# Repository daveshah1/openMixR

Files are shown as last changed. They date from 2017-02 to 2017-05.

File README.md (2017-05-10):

# openMixR 4k Mixed Reality Headset

openMixR is an open software/hardware mixed reality headset powered by an Artix-7 FPGA. It combines a high-resolution (4k) virtual reality headset with
4k cameras and a powerful FPGA to provide augmented reality experiences.

## Current Status

Last year as a university group project a low resolution prototype was built, capable of demos
including a 2D Minecraft game and overlaying content from an HDMI input.

PCB design for revision 1 of the 4k version - which this repo is for - has been finished and PCBs have now arrived. FPGA HDL for the cameras has been developed and tested (albeit
  with a different camera model only capable of 4k30, see [this repo](https://github.com/daveshah1/CSI2Rx)), and HDL for basic LCD functionality has been written
and undergone basic testing. To run the display at 4k will require feeding it with VESA DSC compressed video; code for
this is far from complete so I will be using the display at first in a mode where it upscales from 1080p - which
still looks a lot nicer than a native 1080p LCD. Current LCD code is [here](https://github.com/daveshah1/DSITx).

I am now in the process of testing the PCBs and writing a simple AR demo using the LCD and cameras. At present no breaking
issues in the rev 1.0 PCB have arisen although do take note a few minor errata points - see the hardware folder.

I am also working on a custom HLS tool, not yet released, that will be used to create much of the FPGA processing
code that runs on the headset. An early version of this was used for the aforementioned low res demos.

## Hardware Features

The main components of the hardware are:

 - 4k LCD repurposed from Z5 premium (AUO H546UAN01.0 or unknown Sharp part) on a subassembly allowing different LCDs to be used in the future
 - Dual OV16825 cameras, also on a subassembly so other cameras - in particular I am looking into the Sony IMX318 - could be used
 - Artix-7 FPGA (currently XC7A200T-3FBG484E but cheaper variants could be used)
 - Allwinner A64 quad-core ARM applications processor (with basic GPU for 3D rendering)
 - 512MB of DDR3 attached to the FPGA and 1GB attached to the A64 processor
 - WiFi and Bluetooth
 - USB-C for power, data and DisplayPort video

A photo of the assembled mainboard PCB is below:

Mainboard Photo

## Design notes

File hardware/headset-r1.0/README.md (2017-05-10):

# Hardware for openMixR 1.0

All of the hardware is designed in KiCad 4.0, in the spirit of open source.

- *mainboard* is the headset mainboard, containing the FPGA and processor. It is a 150x90mm 8-layer board
with a minimum track/space of 4mil and a controlled impedance requirement.
- *camboard* is the OV16825 camera subassembly
- *lcdboard* is the Z5 Premium LCD subassembly
- *usbbase* is a board that combines power, USB 2.0 data and Displayport into a USB-C connection,
so openMixR can be used if your computer doesn't support USB-C.

In addition, all of the libraries needed are included. Schematic component libraries are inside the
board folders, with the exception  of *customconn* which is the custom LCD and camera connectors that
interconnect the mainboard and subassemblies. *parts.pretty* contains all of the custom footprints; and *3d*
contains 3D models for many of the components used (for the most part converted from the models provided by their vendors).

PDF schematics are included for all of the boards, if you don't want to install KiCad. Gerbers are also included for all of the boards.

A bill of materials, placement data and impedance control diagrams are also included for the mainboard.

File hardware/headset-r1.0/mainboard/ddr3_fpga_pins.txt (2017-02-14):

##################################################################################################
##
##  Xilinx, Inc. 2010            www.xilinx.com
##  Mon Aug 29 11:18:27 2016
##  Generated by MIG Version 4.0
##
##################################################################################################
##  File name :       mig_7series_0.xdc
##  Details :     Constraints file
##                    FPGA Family:       ARTIX7
##                    FPGA Part:         XC7A100T-FGG484
##                    Speedgrade:        -3
##                    Design Entry:      VHDL
##                    Frequency:         0 MHz
##                    Time Period:       1875 ps
##################################################################################################

##################################################################################################
## Controller 0
## Memory Device: DDR3_SDRAM->Components->MT41K256M16XX-15E
## Data Width: 16
## Time Period: 1875
## Data Mask: 1
##################################################################################################

create_clock -period 2.813 [get_ports sys_clk_p]

#create_clock -period 5 [get_ports clk_ref_i]

############## NET - IOSTANDARD ##################

# PadFunction: IO_L20P_T3_35
set_property SLEW FAST [get_ports {ddr3_dq[0]}]
set_property IN_TERM UNTUNED_SPLIT_50 [get_ports {ddr3_dq[0]}]
set_property IOSTANDARD SSTL15 [get_ports {ddr3_dq[0]}]
set_property PACKAGE_PIN R1 [get_ports {ddr3_dq[0]}]

# PadFunction: IO_L20N_T3_35
set_property SLEW FAST [get_ports {ddr3_dq[1]}]
set_property IN_TERM UNTUNED_SPLIT_50 [get_ports {ddr3_dq[1]}]
set_property IOSTANDARD SSTL15 [get_ports {ddr3_dq[1]}]
set_property PACKAGE_PIN P1 [get_ports {ddr3_dq[1]}]

# PadFunction: IO_L22P_T3_35
set_property SLEW FAST [get_ports {ddr3_dq[2]}]
set_property IN_TERM UNTUNED_SPLIT_50 [get_ports {ddr3_dq[2]}]
set_property IOSTANDARD SSTL15 [get_ports {ddr3_dq[2]}]
set_property PACKAGE_PIN P2 [get_ports {ddr3_dq[2]}]

# PadFunction: IO_L22N_T3_35
set_property SLEW FAST [get_ports {ddr3_dq[3]}]
set_property IN_TERM UNTUNED_SPLIT_50 [get_ports {ddr3_dq[3]}]
set_property IOSTANDARD SSTL15 [get_ports {ddr3_dq[3]}]
set_property PACKAGE_PIN N2 [get_ports {ddr3_dq[3]}]

# PadFunction: IO_L23P_T3_35
set_property SLEW FAST [get_ports {ddr3_dq[4]}]
set_property IN_TERM UNTUNED_SPLIT_50 [get_ports {ddr3_dq[4]}]
set_property IOSTANDARD SSTL15 [get_ports {ddr3_dq[4]}]
set_property PACKAGE_PIN M6 [get_ports {ddr3_dq[4]}]

# PadFunction: IO_L23N_T3_35
set_property SLEW FAST [get_ports {ddr3_dq[5]}]
set_property IN_TERM UNTUNED_SPLIT_50 [get_ports {ddr3_dq[5]}]
set_property IOSTANDARD SSTL15 [get_ports {ddr3_dq[5]}]
set_property PACKAGE_PIN M5 [get_ports {ddr3_dq[5]}]

# PadFunction: IO_L24P_T3_35
set_property SLEW FAST [get_ports {ddr3_dq[6]}]
set_property IN_TERM UNTUNED_SPLIT_50 [get_ports {ddr3_dq[6]}]
set_property IOSTANDARD SSTL15 [get_ports {ddr3_dq[6]}]
set_property PACKAGE_PIN P6 [get_ports {ddr3_dq[6]}]

# PadFunction: IO_L24N_T3_35
set_property SLEW FAST [get_ports {ddr3_dq[7]}]
set_property IN_TERM UNTUNED_SPLIT_50 [get_ports {ddr3_dq[7]}]
set_property IOSTANDARD SSTL15 [get_ports {ddr3_dq[7]}]
set_property PACKAGE_PIN N5 [get_ports {ddr3_dq[7]}]

# PadFunction: IO_L1N_T0_34
set_property SLEW FAST [get_ports {ddr3_dq[8]}]
set_property IN_TERM UNTUNED_SPLIT_50 [get_ports {ddr3_dq[8]}]
set_property IOSTANDARD SSTL15 [get_ports {ddr3_dq[8]}]
set_property PACKAGE_PIN U1 [get_ports {ddr3_dq[8]}]

# PadFunction: IO_L2P_T0_34
set_property SLEW FAST [get_ports {ddr3_dq[9]}]
set_property IN_TERM UNTUNED_SPLIT_50 [get_ports {ddr3_dq[9]}]
set_property IOSTANDARD SSTL15 [get_ports {ddr3_dq[9]}]
set_property PACKAGE_PIN U2 [get_ports {ddr3_dq[9]}]

# PadFunction: IO_L2N_T0_34
set_property SLEW FAST [get_ports {ddr3_dq[10]}]
set_property IN_TERM UNTUNED_SPLIT_50 [get_ports {ddr3_dq[10]}]
set_property IOSTANDARD SSTL15 [get_ports {ddr3_dq[10]}]
set_property PACKAGE_PIN V2 [get_ports {ddr3_dq[10]}]

# PadFunction: IO_L4P_T0_34
set_property SLEW FAST [get_ports {ddr3_dq[11]}]
set_property IN_TERM UNTUNED_SPLIT_50 [get_ports {ddr3_dq[11]}]
set_property IOSTANDARD SSTL15 [get_ports {ddr3_dq[11]}]
set_property PACKAGE_PIN W2 [get_ports {ddr3_dq[11]}]

# PadFunction: IO_L4N_T0_34
set_property SLEW FAST [get_ports {ddr3_dq[12]}]
set_property IN_TERM UNTUNED_SPLIT_50 [get_ports {ddr3_dq[12]}]
set_property IOSTANDARD SSTL15 [get_ports {ddr3_dq[12]}]
set_property PACKAGE_PIN Y2 [get_ports {ddr3_dq[12]}]

# PadFunction: IO_L5P_T0_34
set_property SLEW FAST [get_ports {ddr3_dq[13]}]
set_property IN_TERM UNTUNED_SPLIT_50 [get_ports {ddr3_dq[13]}]
set_property IOSTANDARD SSTL15 [get_ports {ddr3_dq[13]}]
set_property PACKAGE_PIN W1 [get_ports {ddr3_dq[13]}]

# PadFunction: IO_L5N_T0_34
set_property SLEW FAST [get_ports {ddr3_dq[14]}]
set_property IN_TERM UNTUNED_SPLIT_50 [get_ports {ddr3_dq[14]}]
set_property IOSTANDARD SSTL15 [get_ports {ddr3_dq[14]}]
set_property PACKAGE_PIN Y1 [get_ports {ddr3_dq[14]}]

# PadFunction: IO_L6P_T0_34
set_property SLEW FAST [get_ports {ddr3_dq[15]}]
set_property IN_TERM UNTUNED_SPLIT_50 [get_ports {ddr3_dq[15]}]
set_property IOSTANDARD SSTL15 [get_ports {ddr3_dq[15]}]
set_property PACKAGE_PIN U3 [get_ports {ddr3_dq[15]}]

# PadFunction: IO_L1P_T0_AD4P_35
set_property SLEW FAST [get_ports {ddr3_addr[14]}]
set_property IOSTANDARD SSTL15 [get_ports {ddr3_addr[14]}]
set_property PACKAGE_PIN B1 [get_ports {ddr3_addr[14]}]

# PadFunction: IO_L1N_T0_AD4N_35
set_property SLEW FAST [get_ports {ddr3_addr[13]}]
set_property IOSTANDARD SSTL15 [get_ports {ddr3_addr[13]}]
set_property PACKAGE_PIN A1 [get_ports {ddr3_addr[13]}]

# PadFunction: IO_L2P_T0_AD12P_35
set_property SLEW FAST [get_ports {ddr3_addr[12]}]
set_property IOSTANDARD SSTL15 [get_ports {ddr3_addr[12]}]
set_property PACKAGE_PIN C2 [get_ports {ddr3_addr[12]}]

# PadFunction: IO_L2N_T0_AD12N_35
set_property SLEW FAST [get_ports {ddr3_addr[11]}]
set_property IOSTANDARD SSTL15 [get_ports {ddr3_addr[11]}]
set_property PACKAGE_PIN B2 [get_ports {ddr3_addr[11]}]

# PadFunction: IO_L4P_T0_35
set_property SLEW FAST [get_ports {ddr3_addr[10]}]
set_property IOSTANDARD SSTL15 [get_ports {ddr3_addr[10]}]
set_property PACKAGE_PIN E2 [get_ports {ddr3_addr[10]}]

# PadFunction: IO_L4N_T0_35
set_property SLEW FAST [get_ports {ddr3_addr[9]}]
set_property IOSTANDARD SSTL15 [get_ports {ddr3_addr[9]}]
set_property PACKAGE_PIN D2 [get_ports {ddr3_addr[9]}]

# PadFunction: IO_L5P_T0_AD13P_35
set_property SLEW FAST [get_ports {ddr3_addr[8]}]
set_property IOSTANDARD SSTL15 [get_ports {ddr3_addr[8]}]
set_property PACKAGE_PIN G1 [get_ports {ddr3_addr[8]}]

# PadFunction: IO_L5N_T0_AD13N_35
set_property SLEW FAST [get_ports {ddr3_addr[7]}]
set_property IOSTANDARD SSTL15 [get_ports {ddr3_addr[7]}]
set_property PACKAGE_PIN F1 [get_ports {ddr3_addr[7]}]

# PadFunction: IO_L6P_T0_35
set_property SLEW FAST [get_ports {ddr3_addr[6]}]
set_property IOSTANDARD SSTL15 [get_ports {ddr3_addr[6]}]
set_property PACKAGE_PIN F3 [get_ports {ddr3_addr[6]}]

# PadFunction: IO_L7P_T1_AD6P_35
set_property SLEW FAST [get_ports {ddr3_addr[5]}]
set_property IOSTANDARD SSTL15 [get_ports {ddr3_addr[5]}]
set_property PACKAGE_PIN K1 [get_ports {ddr3_addr[5]}]

# PadFunction: IO_L7N_T1_AD6N_35
set_property SLEW FAST [get_ports {ddr3_addr[4]}]
set_property IOSTANDARD SSTL15 [get_ports {ddr3_addr[4]}]
set_property PACKAGE_PIN J1 [get_ports {ddr3_addr[4]}]

# PadFunction: IO_L8P_T1_AD14P_35
set_property SLEW FAST [get_ports {ddr3_addr[3]}]
set_property IOSTANDARD SSTL15 [get_ports {ddr3_addr[3]}]
set_property PACKAGE_PIN H2 [get_ports {ddr3_addr[3]}]

# PadFunction: IO_L8N_T1_AD14N_35
set_property SLEW FAST [get_ports {ddr3_addr[2]}]
set_property IOSTANDARD SSTL15 [get_ports {ddr3_addr[2]}]
set_property PACKAGE_PIN G2 [get_ports {ddr3_addr[2]}]

# PadFunction: IO_L9P_T1_DQS_AD7P_35
set_property SLEW FAST [get_ports {ddr3_addr[1]}]
set_property IOSTANDARD SSTL15 [get_ports {ddr3_addr[1]}]
set_property PACKAGE_PIN K2 [get_ports {ddr3_addr[1]}]

# PadFunction: IO_L9N_T1_DQS_AD7N_35
set_property SLEW FAST [get_ports {ddr3_addr[0]}]
set_property IOSTANDARD SSTL15 [get_ports {ddr3_addr[0]}]
set_property PACKAGE_PIN J2 [get_ports {ddr3_addr[0]}]

# PadFunction: IO_L10P_T1_AD15P_35
set_property SLEW FAST [get_ports {ddr3_ba[2]}]
set_property IOSTANDARD SSTL15 [get_ports {ddr3_ba[2]}]
set_property PACKAGE_PIN J5 [get_ports {ddr3_ba[2]}]

# PadFunction: IO_L10N_T1_AD15N_35
set_property SLEW FAST [get_ports {ddr3_ba[1]}]
set_property IOSTANDARD SSTL15 [get_ports {ddr3_ba[1]}]
set_property PACKAGE_PIN H5 [get_ports {ddr3_ba[1]}]

# PadFunction: IO_L11P_T1_SRCC_35
set_property SLEW FAST [get_ports {ddr3_ba[0]}]
set_property IOSTANDARD SSTL15 [get_ports {ddr3_ba[0]}]
set_property PACKAGE_PIN H3 [get_ports {ddr3_ba[0]}]

# PadFunction: IO_L11N_T1_SRCC_35
set_property SLEW FAST [get_ports {ddr3_ras_n}]
set_property IOSTANDARD SSTL15 [get_ports {ddr3_ras_n}]
set_property PACKAGE_PIN G3 [get_ports {ddr3_ras_n}]

# PadFunction: IO_L12P_T1_MRCC_35
set_property SLEW FAST [get_ports {ddr3_cas_n}]
set_property IOSTANDARD SSTL15 [get_ports {ddr3_cas_n}]
set_property PACKAGE_PIN H4 [get_ports {ddr3_cas_n}]

# PadFunction: IO_L12N_T1_MRCC_35
set_property SLEW FAST [get_ports {ddr3_we_n}]
set_property IOSTANDARD SSTL15 [get_ports {ddr3_we_n}]
set_property PACKAGE_PIN G4 [get_ports {ddr3_we_n}]

# PadFunction: IO_L13P_T2_MRCC_35
set_property SLEW FAST [get_ports {ddr3_reset_n}]
set_property IOSTANDARD LVCMOS15 [get_ports {ddr3_reset_n}]
set_property PACKAGE_PIN K4 [get_ports {ddr3_reset_n}]

# PadFunction: IO_L15N_T2_DQS_35
set_property SLEW FAST [get_ports {ddr3_cke[0]}]
set_property IOSTANDARD SSTL15 [get_ports {ddr3_cke[0]}]
set_property PACKAGE_PIN L1 [get_ports {ddr3_cke[0]}]

# PadFunction: IO_L16P_T2_35
set_property SLEW FAST [get_ports {ddr3_odt[0]}]
set_property IOSTANDARD SSTL15 [get_ports {ddr3_odt[0]}]
set_property PACKAGE_PIN M3 [get_ports {ddr3_odt[0]}]

# PadFunction: IO_L15P_T2_DQS_35
set_property SLEW FAST [get_ports {ddr3_cs_n[0]}]
set_property IOSTANDARD SSTL15 [get_ports {ddr3_cs_n[0]}]
set_property PACKAGE_PIN M1 [get_ports {ddr3_cs_n[0]}]

# PadFunction: IO_L19P_T3_35
set_property SLEW FAST [get_ports {ddr3_dm[0]}]
set_property IOSTANDARD SSTL15 [get_ports {ddr3_dm[0]}]
set_property PACKAGE_PIN N4 [get_ports {ddr3_dm[0]}]

# PadFunction: IO_L1P_T0_34
set_property SLEW FAST [get_ports {ddr3_dm[1]}]
set_property IOSTANDARD SSTL15 [get_ports {ddr3_dm[1]}]
set_property PACKAGE_PIN T1 [get_ports {ddr3_dm[1]}]

# PadFunction: IO_L14P_T2_SRCC_35
set_property IOSTANDARD DIFF_SSTL15 [get_ports {sys_clk_p}]
set_property PACKAGE_PIN L3 [get_ports {sys_clk_p}]

# PadFunction: IO_L14N_T2_SRCC_35
set_property IOSTANDARD DIFF_SSTL15 [get_ports {sys_clk_n}]
set_property PACKAGE_PIN K3 [get_ports {sys_clk_n}]

# PadFunction: IO_L21P_T3_DQS_35
set_property SLEW FAST [get_ports {ddr3_dqs_p[0]}]
set_property IN_TERM UNTUNED_SPLIT_50 [get_ports {ddr3_dqs_p[0]}]
set_property IOSTANDARD DIFF_SSTL15 [get_ports {ddr3_dqs_p[0]}]
set_property PACKAGE_PIN P5 [get_ports {ddr3_dqs_p[0]}]

# PadFunction: IO_L21N_T3_DQS_35
set_property SLEW FAST [get_ports {ddr3_dqs_n[0]}]
set_property IN_TERM UNTUNED_SPLIT_50 [get_ports {ddr3_dqs_n[0]}]
set_property IOSTANDARD DIFF_SSTL15 [get_ports {ddr3_dqs_n[0]}]
set_property PACKAGE_PIN P4 [get_ports {ddr3_dqs_n[0]}]

# PadFunction: IO_L3P_T0_DQS_34
set_property SLEW FAST [get_ports {ddr3_dqs_p[1]}]
set_property IN_TERM UNTUNED_SPLIT_50 [get_ports {ddr3_dqs_p[1]}]
set_property IOSTANDARD DIFF_SSTL15 [get_ports {ddr3_dqs_p[1]}]
set_property PACKAGE_PIN R3 [get_ports {ddr3_dqs_p[1]}]

# PadFunction: IO_L3N_T0_DQS_34
set_property SLEW FAST [get_ports {ddr3_dqs_n[1]}]
set_property IN_TERM UNTUNED_SPLIT_50 [get_ports {ddr3_dqs_n[1]}]
set_property IOSTANDARD DIFF_SSTL15 [get_ports {ddr3_dqs_n[1]}]
set_property PACKAGE_PIN R2 [get_ports {ddr3_dqs_n[1]}]

# PadFunction: IO_L3P_T0_DQS_AD5P_35
set_property SLEW FAST [get_ports {ddr3_ck_p[0]}]
set_property IOSTANDARD DIFF_SSTL15 [get_ports {ddr3_ck_p[0]}]
set_property PACKAGE_PIN E1 [get_ports {ddr3_ck_p[0]}]

# PadFunction: IO_L3N_T0_DQS_AD5N_35
set_property SLEW FAST [get_ports {ddr3_ck_n[0]}]
set_property IOSTANDARD DIFF_SSTL15 [get_ports {ddr3_ck_n[0]}]
set_property PACKAGE_PIN D1 [get_ports {ddr3_ck_n[0]}]

set_property LOC PHASER_OUT_PHY_X1Y7 [get_cells  -hier -filter {NAME =~ */ddr_phy_4lanes_1.u_ddr_phy_4lanes/ddr_byte_lane_D.ddr_byte_lane_D/phaser_out}]
set_property LOC PHASER_OUT_PHY_X1Y11 [get_cells  -hier -filter {NAME =~ */ddr_phy_4lanes_0.u_ddr_phy_4lanes/ddr_byte_lane_D.ddr_byte_lane_D/phaser_out}]
set_property LOC PHASER_OUT_PHY_X1Y10 [get_cells  -hier -filter {NAME =~ */ddr_phy_4lanes_0.u_ddr_phy_4lanes/ddr_byte_lane_C.ddr_byte_lane_C/phaser_out}]
set_property LOC PHASER_OUT_PHY_X1Y9 [get_cells  -hier -filter {NAME =~ */ddr_phy_4lanes_0.u_ddr_phy_4lanes/ddr_byte_lane_B.ddr_byte_lane_B/phaser_out}]
set_property LOC PHASER_OUT_PHY_X1Y8 [get_cells  -hier -filter {NAME =~ */ddr_phy_4lanes_0.u_ddr_phy_4lanes/ddr_byte_lane_A.ddr_byte_lane_A/phaser_out}]

set_property LOC PHASER_IN_PHY_X1Y7 [get_cells  -hier -filter {NAME =~ */ddr_phy_4lanes_1.u_ddr_phy_4lanes/ddr_byte_lane_D.ddr_byte_lane_D/phaser_in_gen.phaser_in}]
## set_property LOC PHASER_IN_PHY_X1Y11 [get_cells  -hier -filter {NAME =~ */ddr_phy_4lanes_0.u_ddr_phy_4lanes/ddr_byte_lane_D.ddr_byte_lane_D/phaser_in_gen.phaser_in}]
## set_property LOC PHASER_IN_PHY_X1Y10 [get_cells  -hier -filter {NAME =~ */ddr_phy_4lanes_0.u_ddr_phy_4lanes/ddr_byte_lane_C.ddr_byte_lane_C/phaser_in_gen.phaser_in}]
## set_property LOC PHASER_IN_PHY_X1Y9 [get_cells  -hier -filter {NAME =~ */ddr_phy_4lanes_0.u_ddr_phy_4lanes/ddr_byte_lane_B.ddr_byte_lane_B/phaser_in_gen.phaser_in}]
set_property LOC PHASER_IN_PHY_X1Y8 [get_cells  -hier -filter {NAME =~ */ddr_phy_4lanes_0.u_ddr_phy_4lanes/ddr_byte_lane_A.ddr_byte_lane_A/phaser_in_gen.phaser_in}]

set_property LOC OUT_FIFO_X1Y7 [get_cells  -hier -filter {NAME =~ */ddr_phy_4lanes_1.u_ddr_phy_4lanes/ddr_byte_lane_D.ddr_byte_lane_D/out_fifo}]
set_property LOC OUT_FIFO_X1Y11 [get_cells  -hier -filter {NAME =~ */ddr_phy_4lanes_0.u_ddr_phy_4lanes/ddr_byte_lane_D.ddr_byte_lane_D/out_fifo}]
set_property LOC OUT_FIFO_X1Y10 [get_cells  -hier -filter {NAME =~ */ddr_phy_4lanes_0.u_ddr_phy_4lanes/ddr_byte_lane_C.ddr_byte_lane_C/out_fifo}]
set_property LOC OUT_FIFO_X1Y9 [get_cells  -hier -filter {NAME =~ */ddr_phy_4lanes_0.u_ddr_phy_4lanes/ddr_byte_lane_B.ddr_byte_lane_B/out_fifo}]
set_property LOC OUT_FIFO_X1Y8 [get_cells  -hier -filter {NAME =~ */ddr_phy_4lanes_0.u_ddr_phy_4lanes/ddr_byte_lane_A.ddr_byte_lane_A/out_fifo}]

set_property LOC IN_FIFO_X1Y7 [get_cells  -hier -filter {NAME =~ */ddr_phy_4lanes_1.u_ddr_phy_4lanes/ddr_byte_lane_D.ddr_byte_lane_D/in_fifo_gen.in_fifo}]
set_property LOC IN_FIFO_X1Y8 [get_cells  -hier -filter {NAME =~ */ddr_phy_4lanes_0.u_ddr_phy_4lanes/ddr_byte_lane_A.ddr_byte_lane_A/in_fifo_gen.in_fifo}]

set_property LOC PHY_CONTROL_X1Y1 [get_cells  -hier -filter {NAME =~ */ddr_phy_4lanes_1.u_ddr_phy_4lanes/phy_control_i}]
set_property LOC PHY_CONTROL_X1Y2 [get_cells  -hier -filter {NAME =~ */ddr_phy_4lanes_0.u_ddr_phy_4lanes/phy_control_i}]

set_property LOC PHASER_REF_X1Y1 [get_cells  -hier -filter {NAME =~ */ddr_phy_4lanes_1.u_ddr_phy_4lanes/phaser_ref_i}]
set_property LOC PHASER_REF_X1Y2 [get_cells  -hier -filter {NAME =~ */ddr_phy_4lanes_0.u_ddr_phy_4lanes/phaser_ref_i}]

set_property LOC OLOGIC_X1Y93 [get_cells  -hier -filter {NAME =~ */ddr_phy_4lanes_1.u_ddr_phy_4lanes/ddr_byte_lane_D.ddr_byte_lane_D/ddr_byte_group_io/*slave_ts}]
set_property LOC OLOGIC_X1Y107 [get_cells  -hier -filter {NAME =~ */ddr_phy_4lanes_0.u_ddr_phy_4lanes/ddr_byte_lane_A.ddr_byte_lane_A/ddr_byte_group_io/*slave_ts}]

set_property LOC PLLE2_ADV_X1Y2 [get_cells -hier -filter {NAME =~ */u_ddr3_infrastructure/plle2_i}]
set_property LOC MMCME2_ADV_X1Y2 [get_cells -hier -filter {NAME =~ */u_ddr3_infrastructure/gen_mmcm.mmcm_i}]

set_multicycle_path -from [get_cells -hier -filter {NAME =~ */mc0/mc_read_idle_r_reg}] \
                    -to   [get_cells -hier -filter {NAME =~ */input_[?].iserdes_dq_.iserdesdq}] \
                    -setup 6

set_multicycle_path -from [get_cells -hier -filter {NAME =~ */mc0/mc_read_idle_r_reg}] \
                    -to   [get_cells -hier -filter {NAME =~ */input_[?].iserdes_dq_.iserdesdq}] \
                    -hold 5

set_false_path -through [get_pins -filter {NAME =~ */DQSFOUND} -of [get_cells -hier -filter {REF_NAME == PHASER_IN_PHY}]]

set_multicycle_path -through [get_pins -filter {NAME =~ */OSERDESRST} -of [get_cells -hier -filter {REF_NAME == PHASER_OUT_PHY}]] -setup 2 -start
set_multicycle_path -through [get_pins -filter {NAME =~ */OSERDESRST} -of [get_cells -hier -filter {REF_NAME == PHASER_OUT_PHY}]] -hold 1 -start

set_max_delay -datapath_only -from [get_cells -hier -filter {NAME =~ *temp_mon_enabled.u_tempmon/* && IS_SEQUENTIAL}] -to [get_cells -hier -filter {NAME =~ *temp_mon_enabled.u_tempmon/device_temp_sync_r1*}] 20
set_max_delay -from [get_cells -hier *rstdiv0_sync_r1_reg*] -to [get_pins -filter {NAME =~ */RESET} -of [get_cells -hier -filter {REF_NAME == PHY_CONTROL}]] -datapath_only 5
set_false_path -through [get_pins -hier -filter {NAME =~ */u_iodelay_ctrl/sys_rst}]

set_max_delay -datapath_only -from [get_cells -hier -filter {NAME =~ *ddr3_infrastructure/rstdiv0_sync_r1_reg*}] -to [get_cells -hier -filter {NAME =~ *temp_mon_enabled.u_tempmon/xadc_supplied_temperature.rst_r1*}] 20

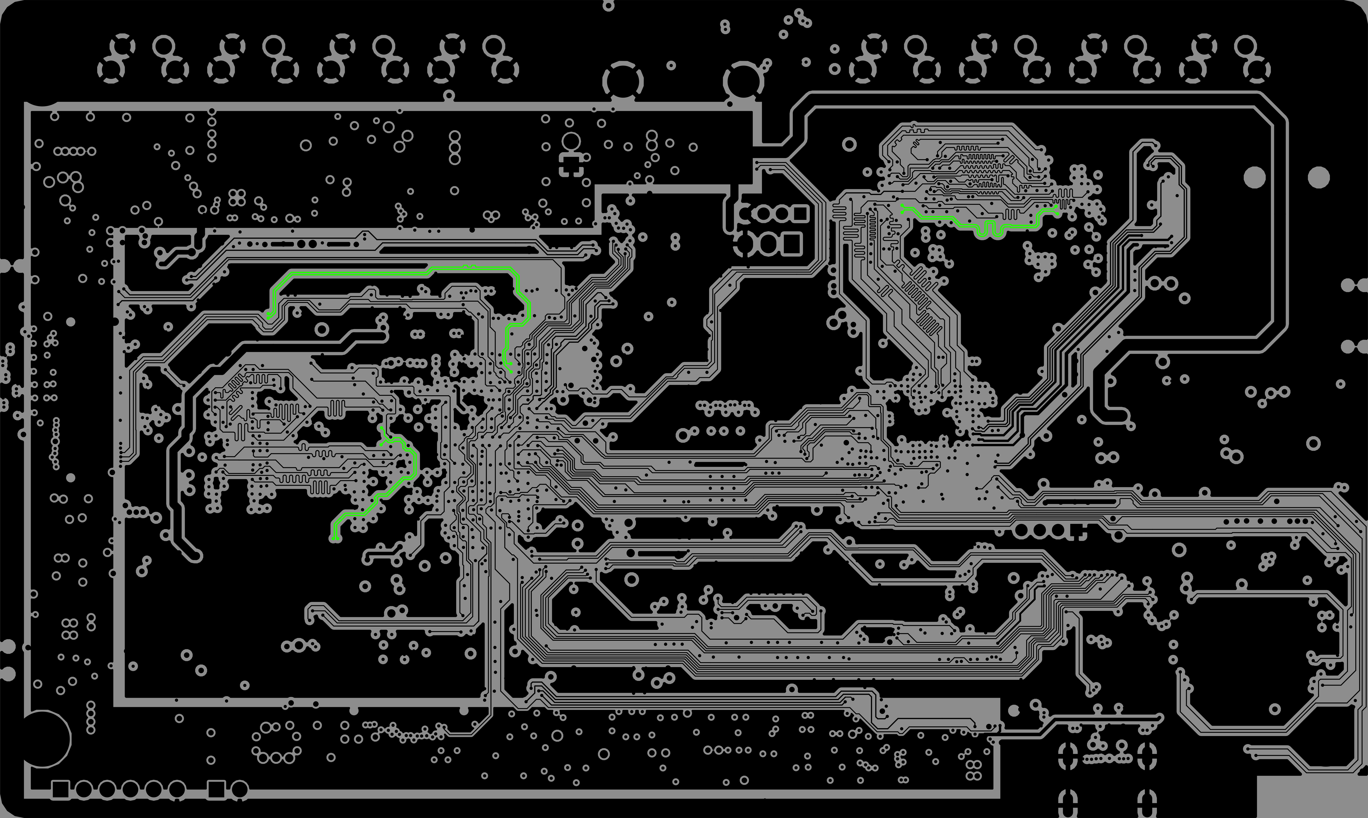
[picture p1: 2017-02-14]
hardware/headset-r1.0/mainboard/impedance/mainboard-In2.Cu-imp.png

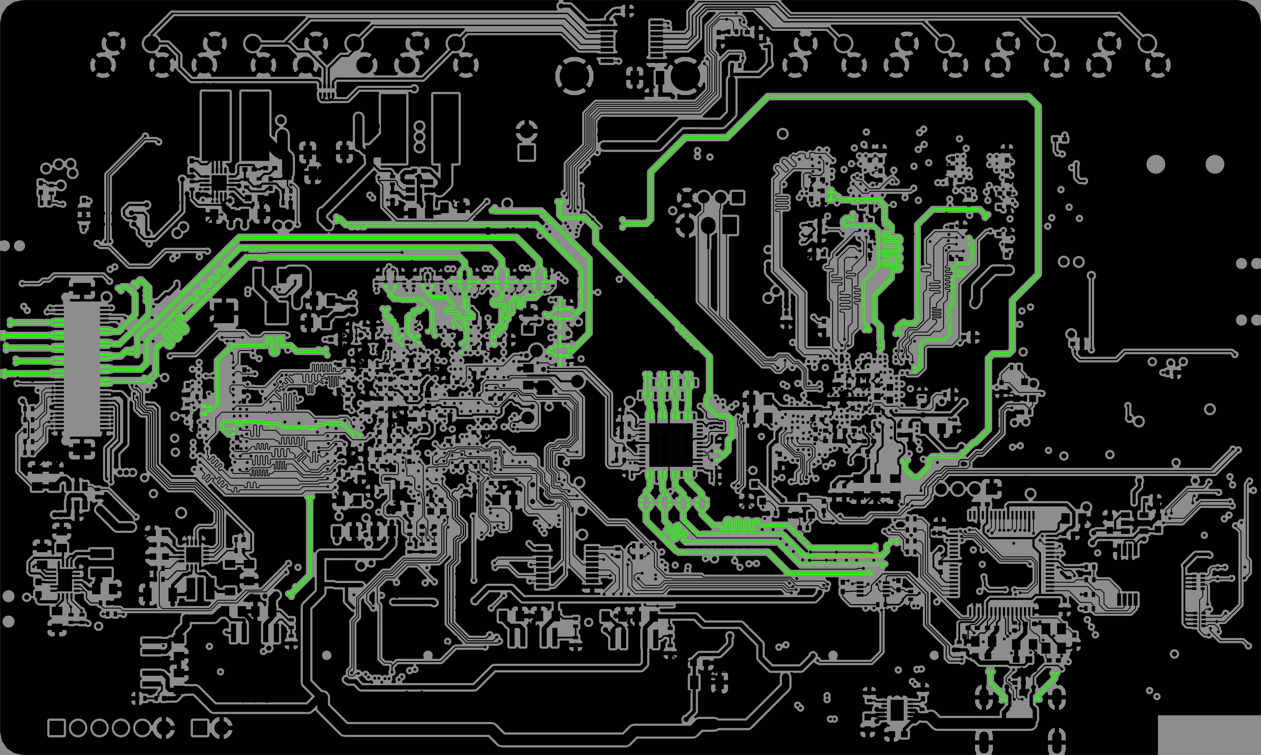
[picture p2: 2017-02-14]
hardware/headset-r1.0/mainboard/impedance/mainboard-B.Cu-imp.png

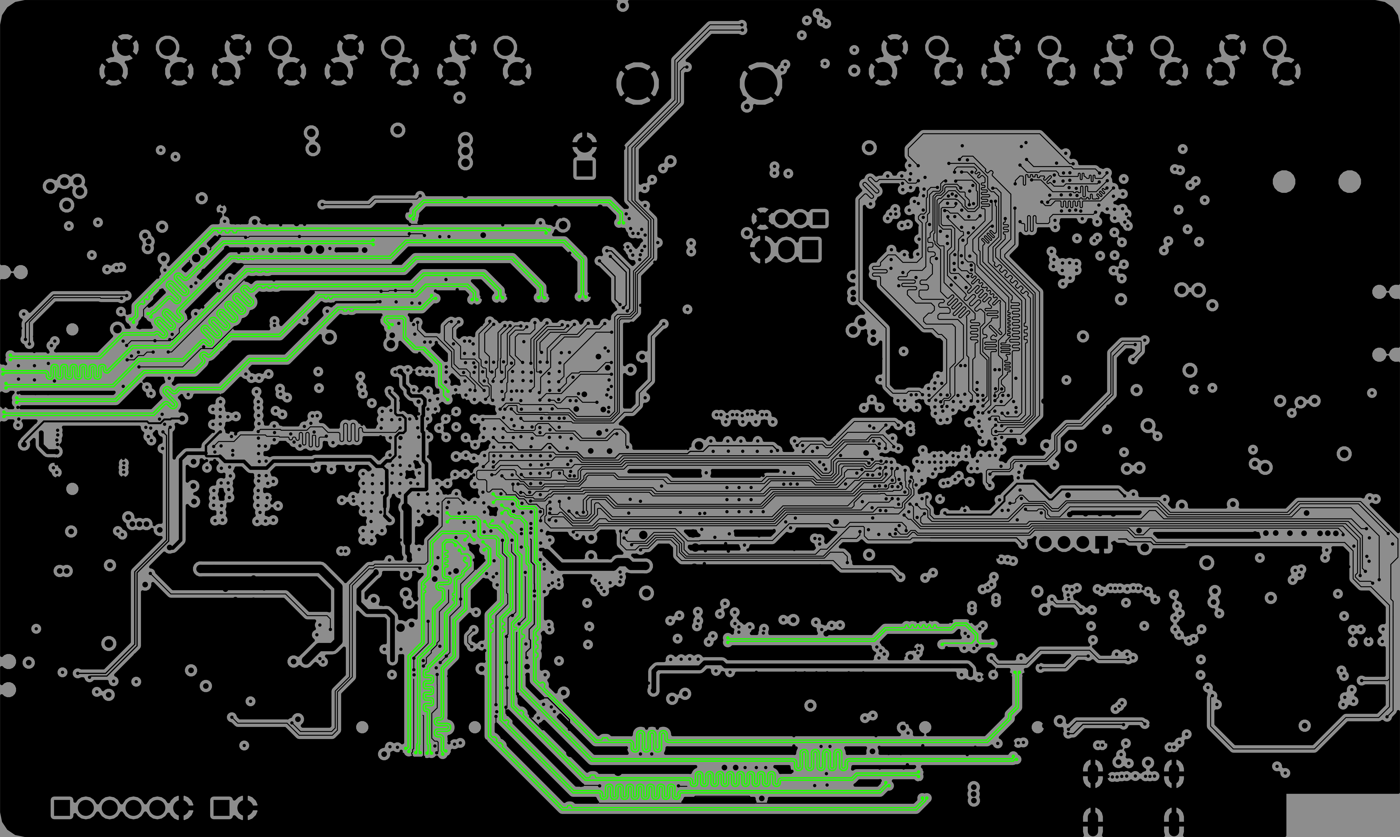
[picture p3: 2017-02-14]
hardware/headset-r1.0/mainboard/impedance/mainboard-In5.Cu-imp.png

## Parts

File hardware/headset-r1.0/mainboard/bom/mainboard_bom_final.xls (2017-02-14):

Id | Designator | Package | Quantity | Designation | Description | Manufacturer | MPN | Notes | Pin/Pad Count | Line Pin/Pad Count
1 | D1901 | LED_RGB_5050 | 1 | QBLP679E-RGB | RGB LED PLCC6 5x5mm | QT Brightek | QBLP679E-RGB | or any other equivalent part | 6 | 6
2 | R1521 | R_0402 | 1 | 20k | 20kΩ 1% 0402 resistor | Yageo | RC0402FR-0720KL | or any other equivalent part | 2 | 2
3 | R1517,R1525 | R_0402 | 2 | 2.87k | 2.87kΩ 1% 0402 resistor | Yageo | RC0402FR-072K87L | or any other equivalent part | 2 | 4
4 | L1505,L1502 | VLP8040 | 2 | 1µH/VLP8040T-1R0 | 1µH 9A 8.6x8.6mm inductor | TDK | VLP8040T-1R0 | or any other equivalent part | 2 | 4
5 | C1516,C203,C205,C206,C207,C208,C211,C633,C634,C719,C1403,C1504,C1508,C1532,C1611,C237 | C_0603 | 16 | 1µ | 1µF 0603 X7R capacitor | Taiyo Yuden | EMK107B7105KA-T | or any other equivalent part | 2 | 32
6 | R1614,R202,R704,R1201,R1202,R1407,R1408,R1410,R1412,R1414,R1512,R221 | R_0402 | 12 | 4.64k | 4.64kΩ 1% 0402 resistor | Yageo | RC0402FR-074K64L | or any other equivalent part | 2 | 24
7 | R1301,R505,R1424,R1207 | R_0402 | 4 | 100 | 100Ω 1% 0402 resistor | Yageo | RC0402FR-07100RL | or any other equivalent part | 2 | 8
8 | U1507,U1503 | QFN-16-1EP_3x3mm_Pitch0.5mm | 2 | TPS53316RGTR | Buck regulator IC | TI | TPS53316RGTR |  | 17 | 34
9 | C1502,C301,C302,C303,C304,C613,C614,C617,C618,C619,C620,C621,C622,C623,C624,C625,C636,C1503,C1505,C1520,C1528,C1538,C1539,C1540,C1602,C1604,C227 | C_0805 | 27 | 10µ | 10µF 0805 capacitor | Murata | GRM21BR71A106MA73L | or any other equivalent part | 2 | 54
10 | C1202,C527,C502,C503,C504,C505,C506,C507,C508,C509,C510,C511,C512,C513,C514,C515,C516,C517,C518,C519,C520,C521,C522,C523,C524,C525,C526,C528,C529,C530,C531,C532,C533,C534,C535,C536,C537,C640,C643,C645,C646,C647,C648,C649,C650,C651,C703,C712,C714,C723,C724,C725,C726,C727,C803,C807,C812,C818,C820,C823,C824,C902,C903,C904,C905,C1101,C1102,C1104,C1107,C1110,C1114,C1115,C1117,C1118,C1119,C1121,C1122,C1124,C1125,C1127,C1128,C1201,C1205,C1206,C1207,C1208,C1209,C1210,C1211,C1212,C1213,C1214,C1215,C1216,C1217,C1307,C1308,C1309,C1310,C1311,C1312,C1313,C1314,C1319,C1320,C1321,C1322,C1323,C1324,C1325,C1326,C1333,C1334,C1336,C1342,C1351,C1352,C1353,C1354,C1601 | C_0402 | 120 | 470n | 470nF 6.3V 0402 capacitor | Murata | GRM155C80J474KE19D | or any other equivalent part | 2 | 240
11 | U1201,U502,U503 | BGA_96_0.8mm | 3 | AS4C256M16D3A-12BCN | 256Mx16 800MHz DDR3 1.5V | Alliance Memory | AS4C256M16D3A-12BCN | can substitute with equivalent DDR3 e.g. | 96 | 288
12 | C639,C221,C224,C225,C501,C638,C641,C642,C644,C701,C711,C713,C715,C718,C720,C721,C801,C805,C821,C822,C901,C1105,C1120,C1303,C1304,C1305,C1306,C1316,C1317,C1318,C1328,C1329,C1331,C1335,C1349,C1350,C1402,C1506,C1522,C1529,C1603,C1606,C1607,C1608,C1612,C1544,C1545 | C_0805 | 47 | 4.7µ | 4.7µF 10V 0805 X7R capacitor | Murata | GRM21BR71A475KA73K | or any other equivalent part | 2 | 94
13 | R502,R506,R507,R1205,R1206 | R_0402 | 5 | 240 | 240kΩ 1% 0402 resistor | Yageo | RC0402FR-07240KL | or any other equivalent part | 2 | 10
14 | U501 | A64_BGA_396 | 1 | A64 | Allwinner A64 Cortex-A53 SoC | Allwinner | A64 |  | 396 | 396
15 | C1330,C1332,C717,C1355,C1356,C1357,C228,C229,C230,C231,C233,C234,C235,C236,C238,C239,C240,C241,C242,C243,C244,C245,C1337,C1338,C1339,C1340,C1341,C1343,C1344,C1345,C1346,C1347,C1358,C1359,C1360 | C_0201 | 35 | 100n | 100nF 0201 capacitor | Murata | GRM033C80J104ME15D | or any other equivalent part | 2 | 70
16 | U1101 | BGA_FGG_484 | 1 | XC7A200T-3FBG484E | Artix-7 FPGA 215k logic cells | Xilinx | XC7A200T-3FBG484E | can substitute with C or I grade | 484 | 484
17 | A801 | 2450AT43B100E | 1 | 2450AT43B100E | 2.4GHz chip antenna | Johanson | 2450AT43B100E |  | 4 | 4
18 | C202,C709,C1203,C1204,C1404,C1405,C1501,C1609 | C_0603 | 8 | 470n | 470nF 16V 0603 X7R capacitor | Taiyo Yuden | EMK107B7474KA-T | or any other equivalent part | 2 | 16
19 | C204,C1519,C1526 | C_0402 | 3 | 160p | 160pF 0402 C0G capacitor | Murata | GRM1555C1H161JA01D | or any other equivalent part | 2 | 6
20 | C212,C213,C214,C215,C216,C217,C219,C220,C222,C226,C601,C612,C707,C708,C809,C1407,C1408,C1409,C1410,C1507,C1510,C1511,C1512,C1527,C1533,C1901,C1903,C1904,C1406 | C_0402 | 29 | 100n | 100nF 10V 0402 X7R capacitor | Murata | GRM155R71A104KA01J | or any other equivalent part | 2 | 58
21 | C218,C223,C817,C819 | C_0402 | 4 | 12p | 12pF 0402 C0G capacitor | Murata | GRM1555C1H120JA01D | or any other equivalent part | 2 | 8
22 | C602,C603,C604,C605,C606,C607,C608,C609,C610,C611,C615,C616,C626,C627,C628,C629,C630,C631,C632,C1108,C1109,C1111,C1112,C1113,C1116,C1123,C1126 | C_0603 | 27 | 4.7µ | 4.7µF 6.3V 0603 capacitor | Samsung | CL10B475KQ8NQNC | or any other equivalent part | 2 | 54
23 | C635,C637,C702,C710,C1106,C1301,C1302,C1315,C1327,C1348,C1401,C1513,C1521,C1530,C1531,C1537,C1541,C1542,C1543,C652 | C_1206 | 20 | 47µ | 47µF 6.3V 1206 capacitor | Samsung | CL31X476KQHNNNE | or any other equivalent part | 2 | 40
24 | C704,C811,C816 | C_0402 | 3 | 22p | 22pF 0402 C0G capacitor | Murata | GRM1555C1H220JA01J | or any other equivalent part | 2 | 6
25 | C705,C706,C802,C806,C808,C810,C813,C814,C815 | C_0402 | 9 | DNP | DO NOT PLACE |  |  |  |  | 0
26 | C716,C722,C1605 | C_0603 | 3 | 2.2µ | 2.2µF 10V 0603 capacitor | Samsung | CL10B225KP8NFNC | or any other equivalent part | 2 | 6
27 | C804,C1515,C1524,C1535 | C_0402 | 4 | 100p | 100pF 0402 C0G capacitor | Murata | GRM1555C1H101JA01D | or any other equivalent part | 2 | 8
28 | C1509 | C_0402 | 1 | 33n | 33nF 0402 capacitor | Murata | GRM155R71C333KA01J | or any other equivalent part | 2 | 2
29 | C1514,C1534 | C_0402 | 2 | 3.3n | 3.3nF 0402 capacitor | Murata | GRM155R71H332KA01D | or any other equivalent part | 2 | 4
30 | C1517,C1525,C209 | C_0402 | 3 | 1.2n | 1.2nF 0402 capacitor | Murata | GRM155R71H122KA01D | or any other equivalent part | 2 | 6
31 | C1518 | C_0402 | 1 | 4.7n | 4.7nF 0402 capacitor | Murata | GRM155R71H472KA01D | or any other equivalent part | 2 | 2
32 | C1523 | C_0402 | 1 | 220n | 220nF 6.3V 0402 capacitor | Murata | GRM155R60J224KE01D | or any other equivalent part | 2 | 2
33 | C1536 | C_0402 | 1 | 3.9n | 3.9nF 0402 capacitor | Murata | GRM155R71H392KA01D | or any other equivalent part | 2 | 2
34 | C1610 | C_1206 | 1 | 4.7µ | 4.7µF 50V 1206 X7R capacitor | Taiyo Yuden | UMK316AB7475KL-T | or any other equivalent part | 2 | 2
35 | D201,D1401,D1402 | LED_0805 | 3 | GREEN | Green 0805 LED | Everlight | QTLP630C4TR | or any other equivalent part | 2 | 6
36 | D202,D701 | X1SON2 | 2 | TPD1E05U06DPYT | ESD protection diode | TI | TPD1E05U06DPYT |  | 2 | 4
37 | D1501 | SOD-523 | 1 | SBR0230T5-7 | 30V 0.2A SOD523 schottky diode | Diodes Inc | SBR0230T5-7 |  | 2 | 2
38 | D1601 | SOD-123 | 1 | MBR0540 | 40V 0.5A SOD123 schottky diode | Fairchild Semi | MBR0540 |  | 2 | 2
39 | DA702,DA703,DA201,DA701 | USON10 | 4 | TPD4E05U06DQAR | Quad ESD protection diode | TI | TPD4E05U06DQAR |  | 10 | 40
40 | J301,J302 | DF17(3.0)-40DS-0.5V(57) | 2 | DF17(3.0)-40DS-0.5V(57) | 40pin 0.5mm receptacle | Hirose | DF17(3.0)-40DS-0.5V(57) |  | 42 | 84
41 | J701 | SJ-43515RS-SMT | 1 | SJ-43515RS-SMT | 4pole 3.5mm audio connector | CUI Inc | SJ-43515RS-SMT |  | 4 | 4
42 | J702 | SCHA4B0419 | 1 | SCHA4B0419 | microSD socket | ALPS | SCHA4B0419 |  | 17 | 17
43 | J1601 | DF17(3.0)-60DS-0.5V(57) | 1 | DF17(3.0)-60DS-0.5V(57) | 60pin 0.5mm receptacle | Hirose | DF17(3.0)-60DS-0.5V(57) |  | 62 | 62
44 | L203,L204,L703,L704 | C_0603 | 4 | 220Ω/100MHz | 220Ω at 100MHz 0603 ferrite | Murata | BLM18KG221SN1D | or any other equivalent part | 2 | 8
45 | L601,L602,L603,L604,L605 | ASPI-4030S | 5 | 1.5µH/ASPI-4030S-1R5N-T | 1.5µH 4.8A 4x4mm inductor | ABRACON | ASPI-4030S-1R5N-T | or any other equivalent part | 2 | 10
46 | L1501,L1504 | SRN8040 | 2 | 1.5µH/SRN8040-1R5 | 1.5µH 7A 8x8mm inductor | Bourns | SRN8040-1R5Y | or any other equivalent part | 2 | 4
47 | L1503 | L_XAL50xx | 1 | 330nH/XAL5030-331MEB | 330nH 19A 5.7x5.5mm inductor | Coilcraft | XAL5030-331MEB | or any other equivalent part | 2 | 2
48 | L1601,L1602 | Neosid_Inductor_SM-NE29_SMD1008 | 2 | 4.7µH/1269AS-H-4R7M | 4.7µH 1A 2.5x2mm inductor | Murata | 1269AS-H-4R7M=P2 | or any other equivalent part | 2 | 4
49 | P201 | Pin_Header_Straight_1x04_Pitch2.00mm | 1 | CCG2_SWD | DO NOT PLACE |  |  |  |  | 0
50 | P702 | Pin_Header_Straight_1x03 | 1 | DNP(UART) | DO NOT PLACE |  |  |  |  | 0
51 | P703 | Pin_Header_Straight_1x04_Pitch2.00mm | 1 | DNP(GPS) | DO NOT PLACE |  |  |  |  | 0
52 | Q601,Q801,Q802,Q1401,Q1402 | SOT-23 | 5 | 2N7002 | SOT-23 N-channel MOSFET | Fairchild Semi | 2N7002 | or any other equivalent part | 3 | 15
53 | Q1501,Q1502 | MOSFET_SGD_SON | 2 | CSD17308Q3 | 30V/13A VSON8 N-channel MOSFET | TI | CSD17308Q3 |  | 3 | 6
54 | Q1503 | SOT-23 | 1 | MMBT3904 | SOT-23 NPN transistor | Fairchild Semi | MMBT3904 | or any other equivalent part | 3 | 3
55 | R201,R205,R206 | R_0402 | 3 | 1M | 1MΩ 1% 0402 resistor | Yageo | RC0402FR-071ML | or any other equivalent part | 2 | 6
56 | R203 | R_0402 | 1 | 82k | 82kΩ 1% 0402 resistor | Yageo | RC0402FR-0782KL | or any other equivalent part | 2 | 2
57 | R204,R213,R503,R504,R602,R607,R809,R1203,R1204,R1514 | R_0402 | 10 | 1k | 1kΩ 1% 0402 resistor | Yageo | RC0402FR-071KL | or any other equivalent part | 2 | 20
58 | R207,R1613,R1901,R1902 | R_0402 | 4 | 100k | 100kΩ 1% 0402 resistor | Yageo | RC0402FR-07100KL | or any other equivalent part | 2 | 8
59 | R208,R209,R210,R211,R305,R307,R308,R310,R312,R313,R601,R604,R606,R701,R810,R811,R902,R905,R906,R1416,R1417,R1420,R1421,R1502,R1503,R1505,R1507,R1508,R1510,R1527,R1528,R1601,R1602,R1603,R1604,R1605,R1607,R1608,R1609,R1610,R1611,R219,R220,R1534,R1418,R232,R233 | R_0402 | 47 | 10k | 10kΩ 1% 0402 resistor | Yageo | RC0402FR-0710KL | or any other equivalent part | 2 | 94
60 | R212,R501,R603,R605,R1513,R222,R223 | R_0402 | 7 | 2k | 2kΩ 1% 0402 resistor | Yageo | RC0402FR-072KL | or any other equivalent part | 2 | 14
61 | R214 | R_0402 | 1 | 12k | 12kΩ 1% 0402 resistor | Yageo | RC0402FR-0712KL | or any other equivalent part | 2 | 2
62 | R215,R216,R217,R218,R709,R805,R1415 | R_0402 | 7 | 22 | 22Ω 1% 0402 resistor | Yageo | RC0402FR-0722RL | or any other equivalent part | 2 | 14
63 | R304,R309 | R_0402 | 2 | 57.6k | 57.6kΩ 1% 0402 resistor | Yageo | RC0402FR-0757K6L | or any other equivalent part | 2 | 4
64 | R306,R311,R702,R710,R901,R903,R904,R907,R1402,R1404,R1405,R1515 | R_0402 | 12 | 0R | 0Ω 0402 resistor | Yageo | RC0402FR-070RL | or any other equivalent part | 2 | 24
65 | R508,R509 | R_0402 | 2 | NC/240 | DO NOT PLACE |  |  |  |  | 0
66 | R703,R706,R803,R806,R807,R808,R1401,R1403,R1406 | R_0402 | 9 | DNP | DO NOT PLACE |  |  |  |  | 0
67 | R705,R707,R708,R1612 | R_0402 | 4 | 33k | 33kΩ 1% 0402 resistor | Yageo | RC0402FR-0733KL | or any other equivalent part | 2 | 8
68 | R711 | R_0402 | 1 | 200k | 200kΩ 1% 0402 resistor | Yageo | RC0402FR-07200KL | or any other equivalent part | 2 | 2
69 | R804 | R_0402 | 1 | 10M | 10MΩ 1% 0402 resistor | Yageo | RC0402FR-0710ML | or any other equivalent part | 2 | 2
70 | R1409,R1530 | R_0402 | 2 | 2.49k | 2.49kΩ 1% 0402 resistor | Yageo | RC0402FR-072K49L | or any other equivalent part | 2 | 4
71 | R1411,R1413,R1518 | R_0402 | 3 | 464 | 464Ω 1% 0402 resistor | Yageo | RC0402FR-07464RL | or any other equivalent part | 2 | 6
72 | R1501 | R_0402 | 1 | 2.2 | 2.2Ω 1% 0402 resistor | Yageo | RC0402FR-072R2L | or any other equivalent part | 2 | 2
73 | R1504 | R_0402 | 1 | 84.5k | 84.5kΩ 1% 0402 resistor | Yageo | RC0402FR-0784K5L | or any other equivalent part | 2 | 2
74 | R1506 | R_0402 | 1 | 11k | 11kΩ 1% 0402 resistor | Yageo | RC0402FR-0711KL | or any other equivalent part | 2 | 2
75 | R1509 | R_0402 | 1 | 5.76k | 5.76kΩ 1% 0402 resistor | Yageo | RC0402FR-075K76L | or any other equivalent part | 2 | 2
76 | R1511,R1529 | R_0402 | 2 | 3.01k | 3.01kΩ 1% 0402 resistor | Yageo | RC0402FR-073K01L | or any other equivalent part | 2 | 4
77 | R1516,R1904,R1905 | R_0402 | 3 | 205 | 205Ω 1% 0402 resistor | Yageo | RC0402FR-07205RL | or any other equivalent part | 2 | 6
78 | R1519,R1520,R1524 | R_0402 | 3 | 4.32k | 4.32kΩ 1% 0402 resistor | Yageo | RC0402FR-074K32L | or any other equivalent part | 2 | 6
79 | R1522 | R_0402 | 1 | 30k | 30kΩ 1% 0402 resistor | Yageo | RC0402FR-0730KL | or any other equivalent part | 2 | 2
80 | R1523 | R_0402 | 1 | 187 | 187Ω 1% 0402 resistor | Yageo | RC0402FR-07187RL | or any other equivalent part | 2 | 2
81 | R1526 | R_0402 | 1 | 9.76k | 9.76kΩ 1% 0402 resistor | Yageo | RC0402FR-079K76L | or any other equivalent part | 2 | 2
82 | R1531 | R_0402 | 1 | 560 | 560Ω 1% 0402 resistor | Yageo | RC0402FR-07560RL | or any other equivalent part | 2 | 2
83 | R1532,R1903 | R_0402 | 2 | 249 | 249Ω 1% 0402 resistor | Yageo | RC0402FR-07249RL | or any other equivalent part | 2 | 4
84 | R1606 | R_0402 | 1 | 620k | 620kΩ 1% 0402 resistor | Yageo | RC0402FR-07620KL | or any other equivalent part | 2 | 2
85 | RP1901,RP1902,R801,R802 | R_Array_Concave_4x0402 | 4 | 47k | 47kΩx4 5% 0804 resistor array | Panasonic | EXB-N8V473JX | or any other equivalent part | 2 | 8
86 | SW1501 | SSSS810701 | 1 | SSSS810701 | SMT SPDT slide switch | ALPS | SSSS810701 | or any other equivalent part | 3 | 3
87 | SW1901,SW1902,SW1903,SW1904,SW1905,SW1906,SW1907,SW1908 | PTS645VM83 | 8 | PTS645VM83-2 | TH SPST tact switch | C&K | PTS645VM83-2 LFS | or any other equivalent part | 4 | 32
88 | U201 | DFN-10-1EP_3x3mm_Pitch0.5mm | 1 | TPS259250DRCT | 5V/5A eFuse | TI | TPS259250DRCT |  | 11 | 11
89 | U202 | SOT-23-5 | 1 | LD3985M33R | 3.3V/150mA SOT-23-5 LDO | ST | LD3985M33R |  | 5 | 5
90 | U203 | QFN-24-1EP_4x4mm_Pitch0.5mm | 1 | CYPD2119-24LQXIT | USB-C interface IC | Cypress | CYPD2119-24LQXIT |  | 25 | 25
91 | U204 | VSSOP8_2.3x2mm_0.5mm | 1 | TS5A23166DCUR | Dual SPST analog switch | TI | TS5A23166DCUR |  | 8 | 8
92 | U205 | TSSOP-8_4.4x3mm_Pitch0.65mm | 1 | M93C46-WDW6TP | 1kbit SPI EEPROM | ST | M93C46-WDW6TP | or any other equivalent part | 8 | 8
93 | U206 | LQFP-64_10x10mm_Pitch0.5mm | 1 | FT2232HL | USB HS interface IC | FTDI | FT2232HL |  | 64 | 64
94 | U301,U302,U1506,U1508 | SOT-223-6 | 4 | MCP1825T-ADJE/DC | Adjustable 500mA LDO | Microchip | MCP1825T-ADJE/DC |  | 6 | 24
95 | U601 | QFN68_8x8mm_0.4mm | 1 | AXP803 | Allwinner SoC PMIC | X-powers | AXP803 |  | 69 | 69
96 | U701 | SOT-23-6 | 1 | TPD3S014DBVR | USB host current monitor | TI | TPD3S014DBVR |  | 6 | 6
97 | U801 | RTL8723BS_MOD | 1 | SM02BD | 44pin SDIO RTL8723BS WLAN+BT module | Radiolink | RL-SM02BD-8723BS | or any other equivalent part | 44 | 44
98 | U901,U1401 | SOT-23 | 2 | STM1061N31WX6F | 3.1V active low voltage detector | ST | STM1061N31WX6F |  | 3 | 6
99 | U1402 | VDFPN8 | 1 | N25Q256A13EF840E | 256Mbit SQI flash | Micron | N25Q256A13EF840E |  | 9 | 9
100 | U1501 | SOT-23-6 | 1 | LM3880MF-1AA | Power supply sequencer IC | TI | LM3880MF-1AA |  | 6 | 6
101 | U1502,U1505 | SOT-23-6 | 2 | TPS563200DDCR | Buck regulator IC | TI | TPS563200DDCR |  | 6 | 12
102 | U1504 | QFN-24-1EP_4x4mm_Pitch0.5mm | 1 | LM27403SQ | Buck regulator controller IC | TI | LM27403SQ |  | 25 | 25
103 | U1601 | SOT-23-6 | 1 | TPS22929DDBVR | High-side 1.8A load switch IC | TI | TPS22929DDBVR |  | 6 | 6
104 | U1602 | QFN-20-1EP_3x4mm_Pitch0.5mm | 1 | TPS65132WRVCR | LCD bias generator IC | TI | TPS65132WRVCR |  | 21 | 21
105 | U1603 | QFN-16-1EP_3x3mm_Pitch0.5mm | 1 | TPS61176RTER | 6-channel WLED driver IC | TI | TPS61176RTER |  | 17 | 17
106 | U1901 | QFN-24-1EP_3x3mm_Pitch0.4mm | 1 | MPU9250 | 9-axis IMU | InvenSense | MPU9250 |  | 25 | 25
107 | X201 | XTAL_ABM8_3.2x2.5mm | 1 | ABM8G-12.000MHZ-18-D2Y-T | 12MHz 3.2x2.5mm crystal | ABRACON | ABM8G-12.000MHZ-18-D2Y-T | or any other equivalent part | 4 | 4
108 | X801 | XTAL_ABM8_3.2x2.5mm | 1 | ABM8G-24.000MHZ-18-D2Y-T | 24MHz 3.2x2.5mm crystal | ABRACON | ABM8G-24.000MHZ-18-D2Y-T | or any other equivalent part | 4 | 4
109 | X1401 | DSC11x3C_3.2x2.5mm | 1 | DSC1123CI2-200.0000 | 200MHz LVDS oscillator | Microchip | DSC1123CI2-200.0000 |  | 6 | 6
110 | X1402 | DSC11x3C_3.2x2.5mm | 1 | DSC1123CI2-150.0000 | 150MHz LVDS oscillator | Microchip | DSC1123CI2-150.0000 |  | 6 | 6
111 | Y802 | XTAL_ABS07 | 1 | ABS07-32.768KHZ-T | 32.768kHz crystal | ABRACON | ABS07-32.768KHZ-T | or any other equivalent part | 2 | 2
112 | C1103 | TantalC_SizeD_EIA-7343_Reflow | 1 | 330µ | 330µF 4V 7343 aluminium polymer capacitor | Panasonic | EEF-CX0G331R | or any other equivalent part | 2 | 2
113 | P701 | 292303-7 | 1 | 292303-7 | USB type-A socket | TE Connectivity | 292303-7 | or any other equivalent part | 6 | 6
114 | J201 | USBC-105450-0101 | 1 | 105450-0101 | USB 3.1 type-C socket | Molex | 105450-0101 |  | 28 | 28
115 | DA203,DA202 | USON10 | 2 | TPD4E02B04DQAR | Quad ESD protection diode | TI | TPD4E02B04DQAR |  | 10 | 20
116 | SW801,SW802,SW1401 | SKSCLDE010 | 3 | SKSCLDE010 | SMD right angle tact switch | ALPS | SKSCLDE010 | or any other equivalent part | 4 | 12
117 | P101,P102,P103,P104 | M3_HOLE | 4 | GND | DO NOT PLACE |  |  |  |  | 0
118 | R1701,R1704,R1705,R1708,R1709,R1712,R1713,R1716,R1717,R1720,R1801,R1804,R1805,R1808,R1809,R1812,R1813,R1816,R1817,R1820 | R_0201 | 20 | 22 | 22Ω 1% 0201 resistor | Yageo | RC0201FR-0722RL | or any other equivalent part | 2 | 40
119 | R1702,R1703,R1706,R1707,R1710,R1711,R1714,R1715,R1718,R1719,R1802,R1803,R1806,R1807,R1810,R1811,R1814,R1815,R1818,R1819 | R_0201 | 20 | 120 | 120Ω 1% 0201 resistor | Yageo | RC0201FR-07120RL | or any other equivalent part | 2 | 40
120 | R1721,R1722,R1723,R1724,R1725,R1726,R1727,R1728,R1729,R1730,R1821,R1822,R1823,R1824,R1825,R1826,R1827,R1828,R1829,R1830,R224,R225,R226,R227,R228,R229,R230,R231 | R_0201 | 28 | 51 | 51Ω 1% 0201 resistor | Yageo | RC0201FR-0751RL | or any other equivalent part | 2 | 56
121 | U207 | QFN-48-1EP_7x7mm_Pitch0.5mm | 1 | SN75DP159RGZT | 6Gbps DP retimer | TI | SN75DP159RGZT |  | 49 | 49
122 | U1902 | TSSOP-16_4.4x5mm_Pitch0.65mm | 1 | 74HC165PW | 8-bit parallel-load shift register | NXP | 74HC165PW,118 | or any other equivalent part | 17 | 17
123 | R1533 | R_0402 | 1 | 51k | 51kΩ 1% 0402 resistor | Yageo | RC0402FR-0751KL | or any other equivalent part | 2 | 2
124 | U1403 | TSSOP-16_4.4x5mm_Pitch0.65mm | 1 | TS3A5018PWR | Quad SPDT analog switch | TI | TS3A5018PWR |  | 16 | 16
125 | P1401 | Pin_Header_Straight_1x06_Pitch2.54mm | 1 | CONN_01X06 | 6-pin 2.54mm pin header | Harwin | M20-9990645 | or any other equivalent part | 6 | 6
126 | JP1401 | Pin_Header_Straight_1x02_Pitch2.54mm | 1 | JTAG_MODE | 2-pin 2.54mm pin header | Harwin | M20-9990245 | or any other equivalent part | 2 | 2
127 | R1101 | R_1206 | 1 | 0.47 | 0.47Ω 1206 resistor | Panasonic | ERJ-8RQFR47V | or any other equivalent part | 2 | 2
128 | C210 | CP_Elec_6.3x5.3 | 1 | 150µ | 150uF 6.3V 6.3mm SMD electrolytic capacitor | Nichicon | UWJ0J151MCL1GB | or any other equivalent part | 2 | 4
129 | C232,C1902 | C_0201 | 2 | 10n | 10nF 0201 capacitor | Murata | GRM033R71A103KA01D | or any other equivalent part | 2 | 2
130 | P1501 | Pin_Header_Straight_1x02_Pitch2.54mm | 1 | FAN | DO NOT PLACE |  |  |  |  | 0
131 | W1302 | Measurement_Point_Round-SMD-Pad_Small | 1 | IO2 | DO NOT PLACE |  |  |  |  | 0
132 | W1304 | Measurement_Point_Round-SMD-Pad_Small | 1 | IO1 | DO NOT PLACE |  |  |  |  | 0
133 | W1305 | Measurement_Point_Round-SMD-Pad_Small | 1 | IO0 | DO NOT PLACE |  |  |  |  | 0
134 | W1301 | Measurement_Point_Round-SMD-Pad_Small | 1 | IO5 | DO NOT PLACE |  |  |  |  | 0
135 | W1303 | Measurement_Point_Round-SMD-Pad_Small | 1 | IO4 | DO NOT PLACE |  |  |  |  | 0
136 | W1306 | Measurement_Point_Round-SMD-Pad_Small | 1 | IO3 | DO NOT PLACE |  |  |  |  | 0
 |  |  |  |  |  |  |  |  |  | 0

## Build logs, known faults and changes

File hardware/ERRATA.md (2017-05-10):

# Hardware Errata

## Revision 1.0
 - BOM line 13, R502,R506,R507,R1205,R1206 has the correct designation 240, this is also correct within KiCad,
however the description and MPN errneously refer to a 240kΩ resistor. These parts should be a 240Ω resistor (Yageo MPN RC0402FR-07240RL)
 - P703 is designated GPS and P702 is designated UART, and the signals connected to P702 titled "A64_DBG_TX" and "A64_DBG_RX". However please
note that with an unmodified bootloader and Linux configuration, debug messages will come out of the GPS connector.
 - Due to a significant inrush current, the board's UVP may prevent it from starting up when using a weak USB port or inadequate cable. As the
device may require significant operating current, using a sufficiently strong port (e.g. a phone charger, a USB3 port on the **back** of a desktop,
  or a genuine USB type-C port) with a good cable is always recommended. It may be possible to get the board to start on a weaker port by increasing
  C204 but this has not been tested.
 - The power switch only switches power to the FPGA subsystem, not the A64 subsystem (although arguably this could be exploited to "softly" shut down the A64),
  and does not control the power LED.

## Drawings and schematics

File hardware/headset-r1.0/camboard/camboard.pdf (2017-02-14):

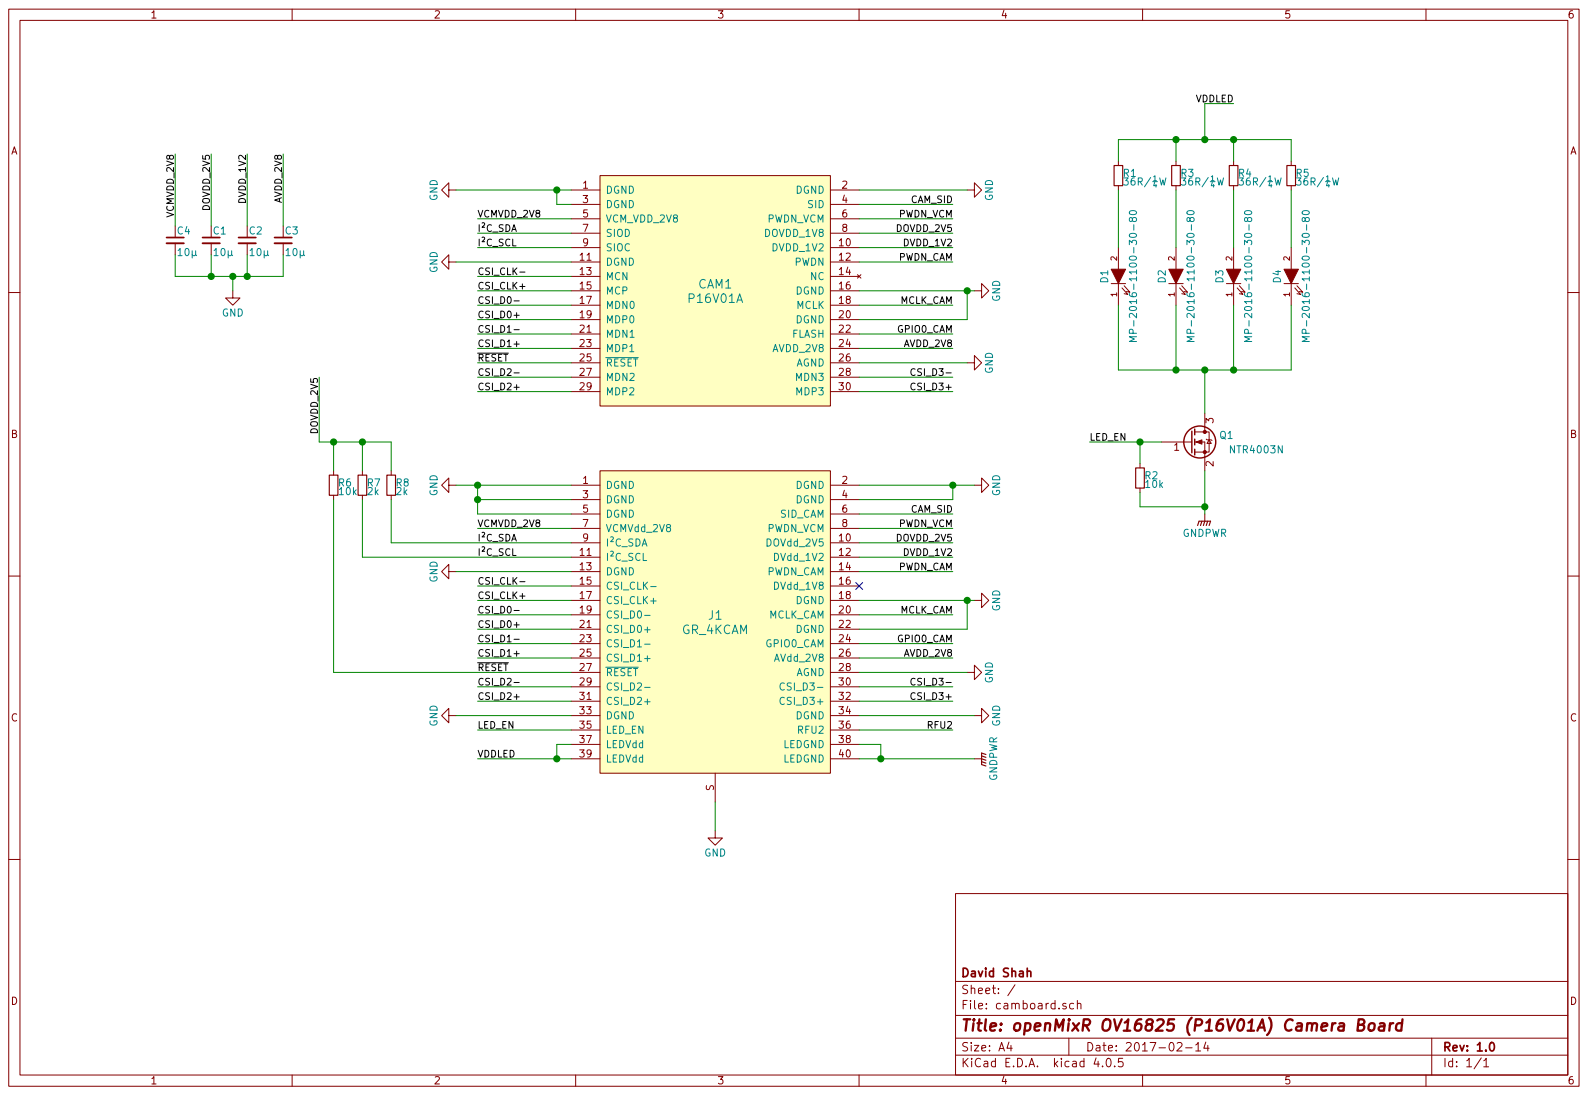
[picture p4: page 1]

File: camboard.sch Sheet: / David Shah

Id: 1/1 Title: openMixR OV16825 (P16V01A) Camera Board

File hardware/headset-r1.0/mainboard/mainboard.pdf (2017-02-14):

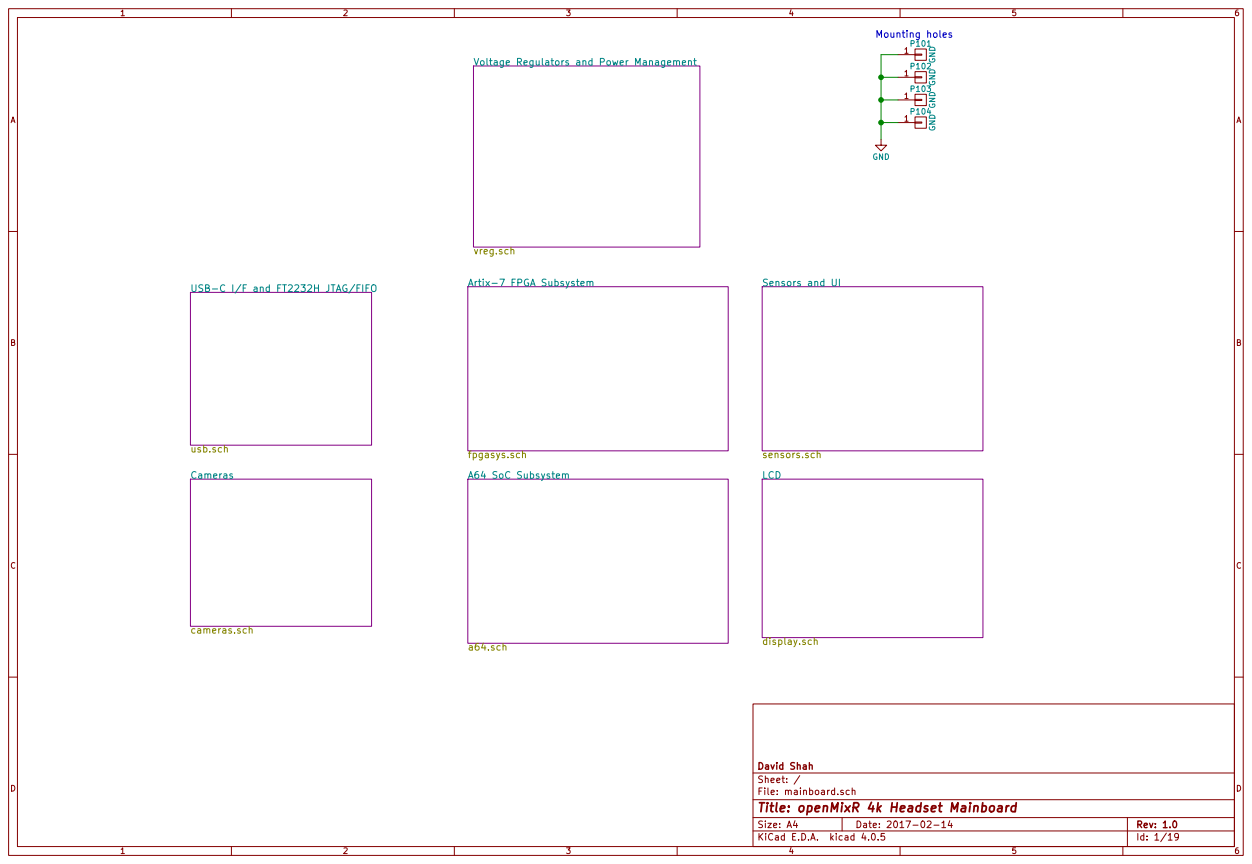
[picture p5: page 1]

1 P104 GND GND Mounting holes

Voltage Regulators and Power Management

vreg.sch
a64.sch Artix-7 FPGA Subsystem

USB-C I/F and FT2232H JTAG/FIFO

Sensors and UI sensors.sch

File: mainboard.sch Sheet: / David Shah

Id: 1/19 Title: openMixR 4k Headset Mainboard

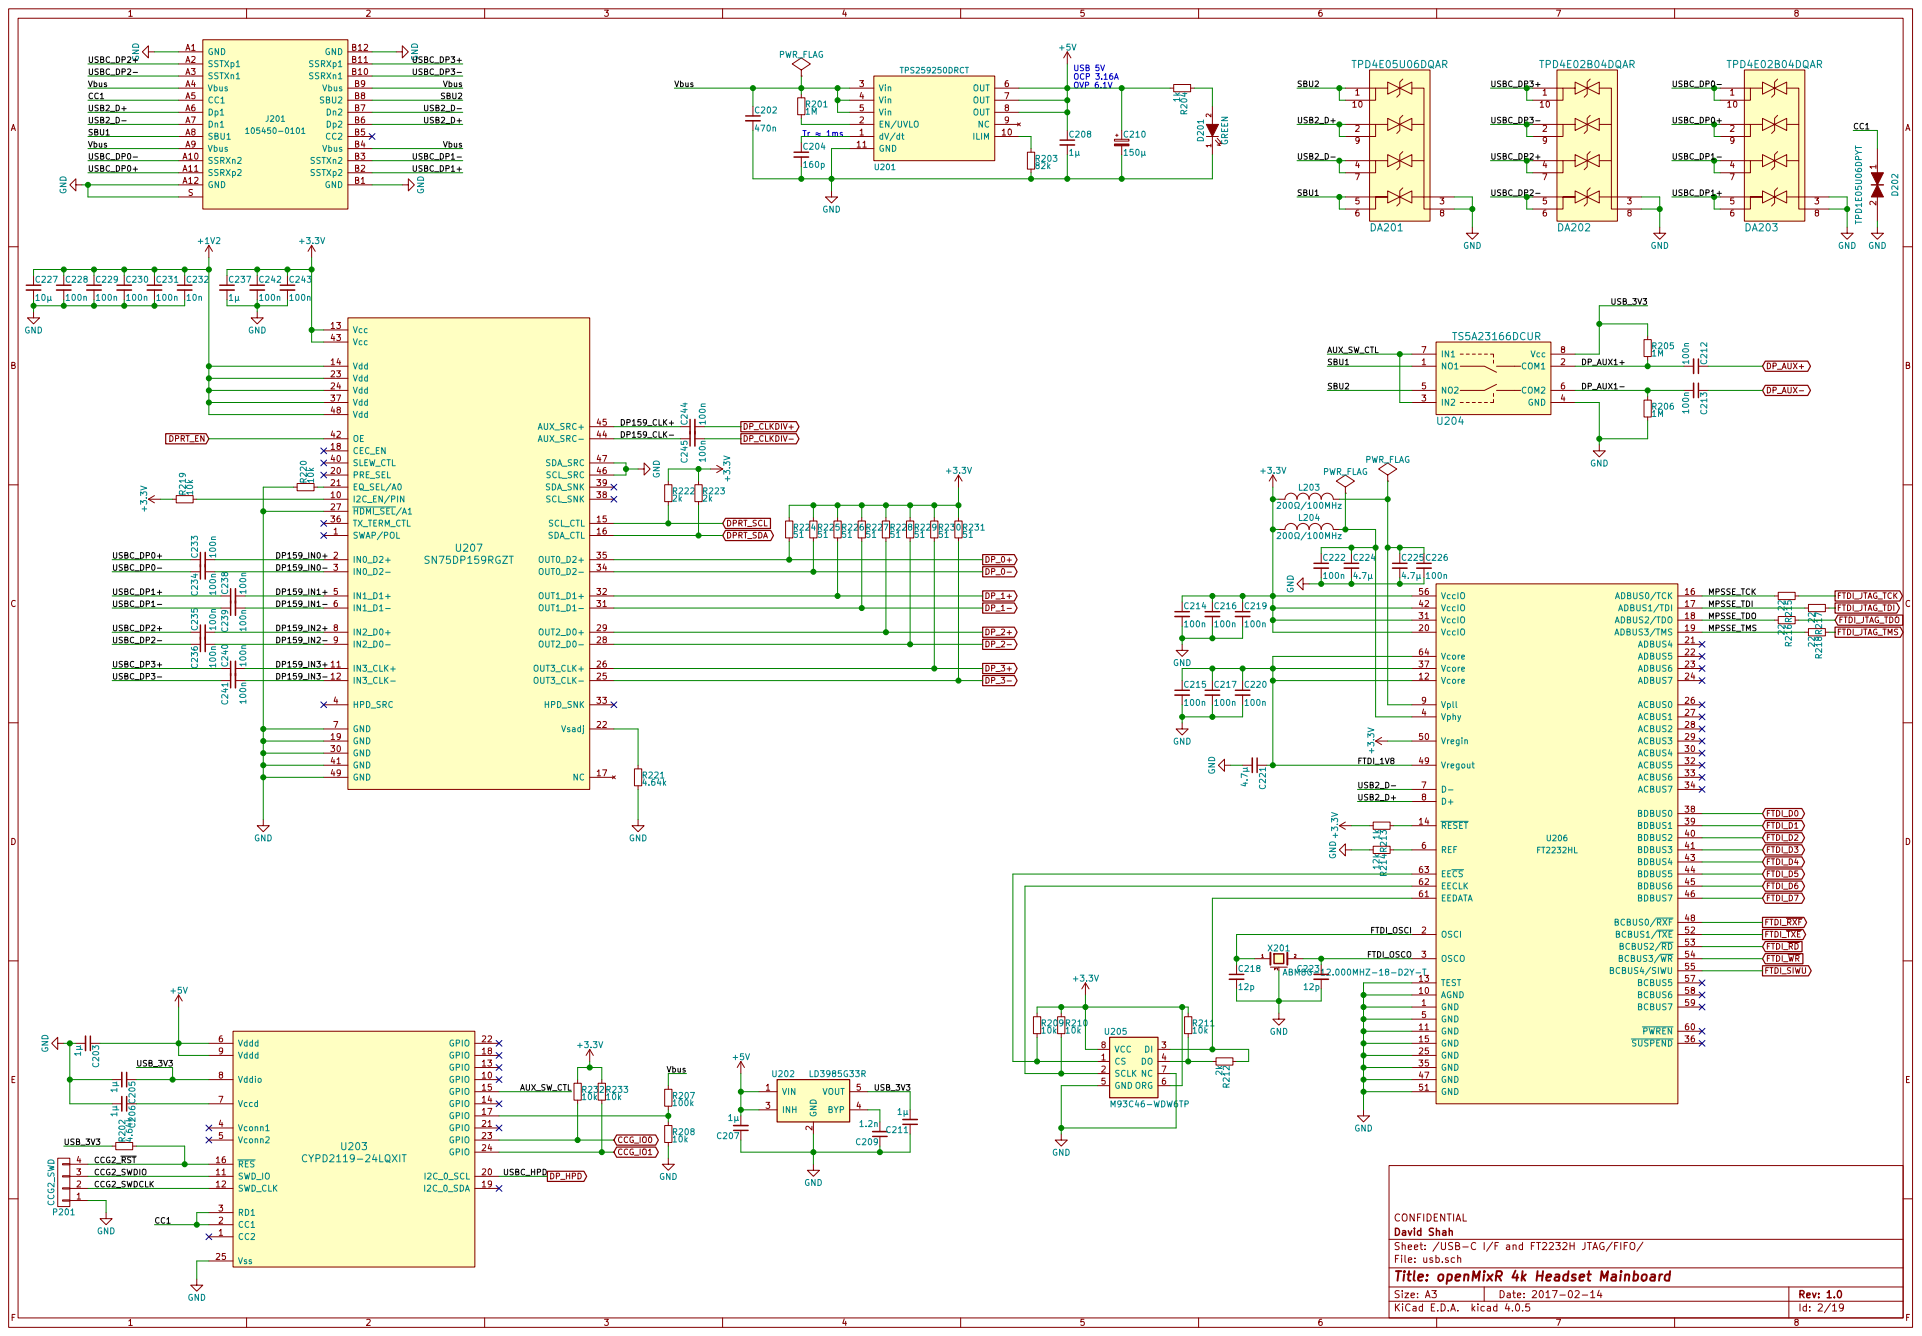
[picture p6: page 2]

4 P201 CCG2_SWD 2 CCG2_SWDCLK

Id: 2/19 Title: openMixR 4k Headset Mainboard

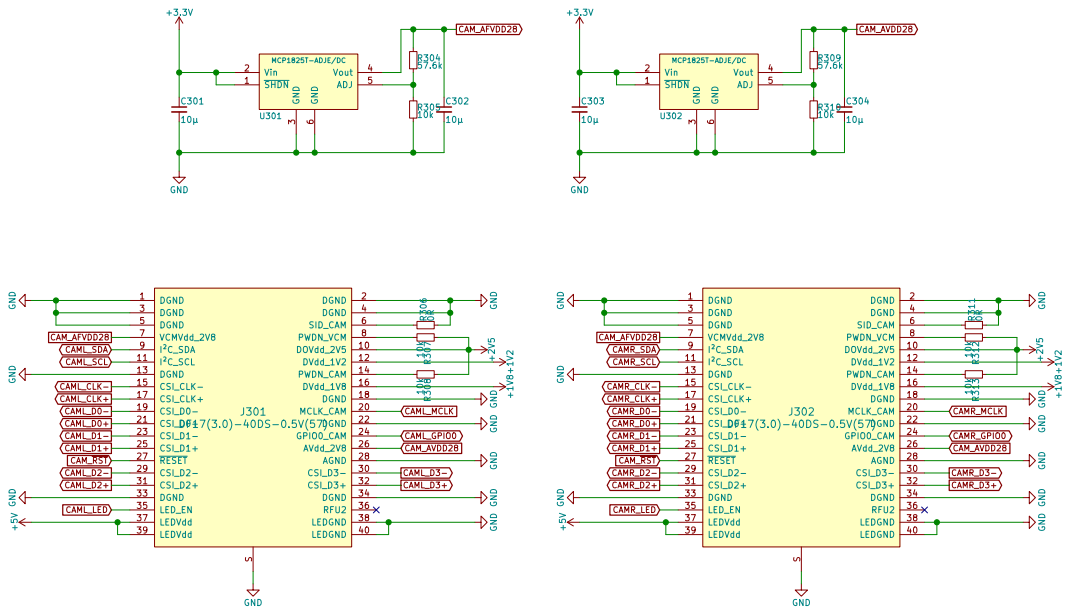
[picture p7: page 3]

File: cameras.sch Sheet: /Cameras/ David Shah CONFIDENTIAL

Id: 3/19 Title: openMixR 4k Headset Mainboard

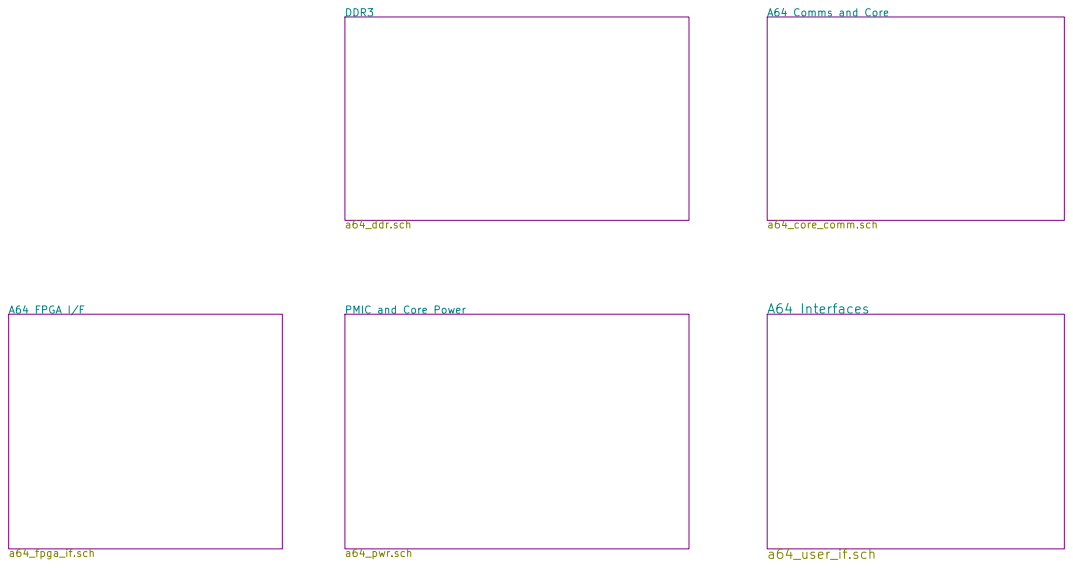
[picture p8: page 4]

File: a64.sch Sheet: /A64 SoC Subsystem/ David Shah CONFIDENTIAL

Id: 4/19 Title: openMixR 4k Headset Mainboard

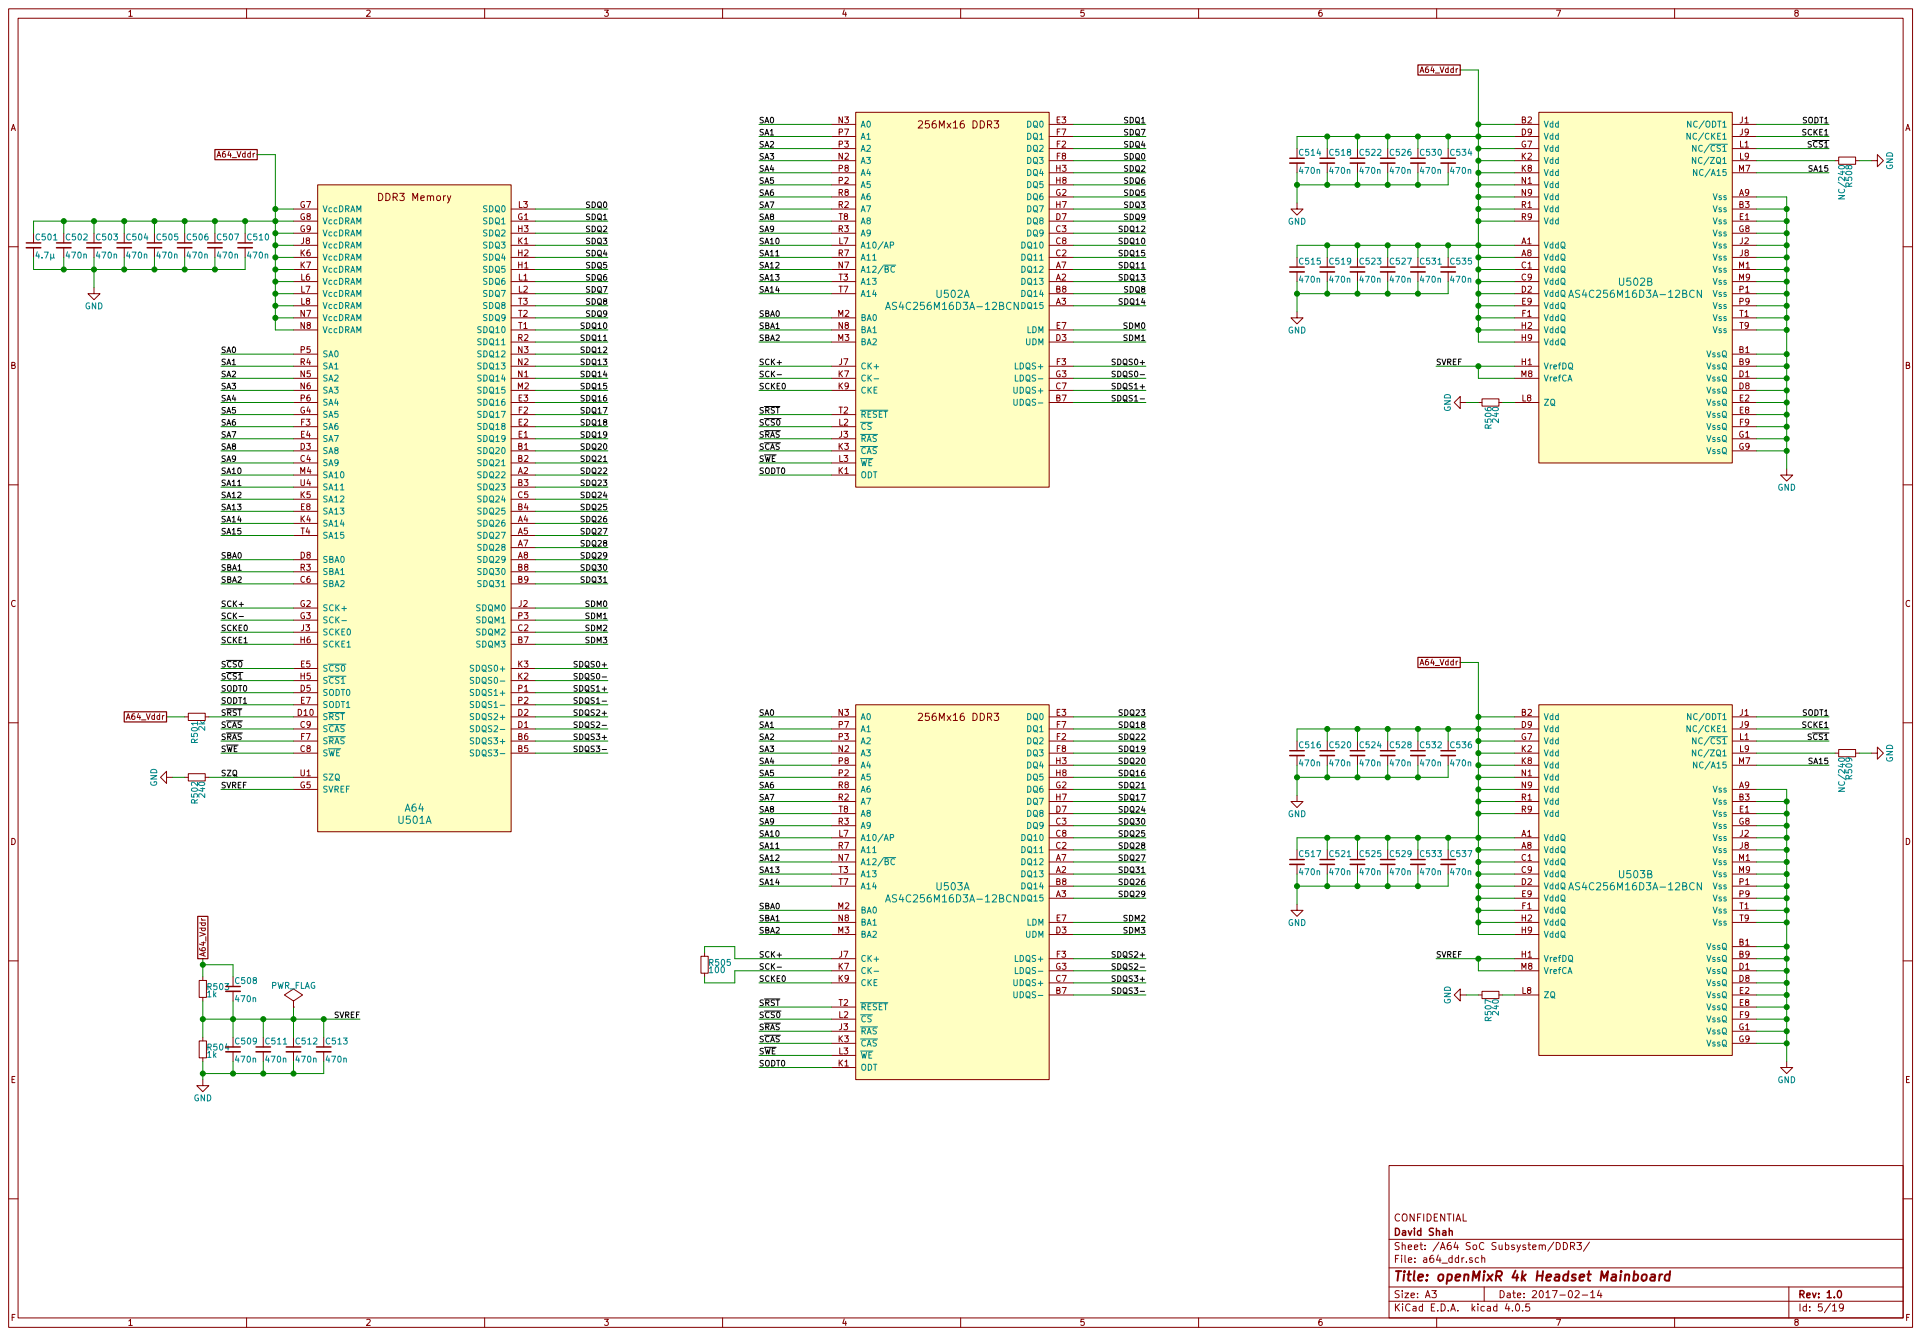
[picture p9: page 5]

SA0 SA1 SA2 SA3 SA4 SA5 SA6 SA7 SA8 SA9 SA10 SA11 SA12 SA13 SA14 SBA0 SBA1 SBA2 SCK+ SCK- SCKE0 SRST SCS0 SRAS

SCAS
SWE
SODT0 SA0 SA1 SA2 SA3 SA4 SA5 SA6 SA7 SA8 SA9 SA10 SA11 SA12 SA13 SA14 SBA0 SBA1 SBA2 SCK+ SCK- SCKE0 SRST SCS0 SRAS

Sheet: /A64 SoC Subsystem/DDR3/ David Shah CONFIDENTIAL

File: a64_ddr.sch
Id: 5/19 Title: openMixR 4k Headset Mainboard

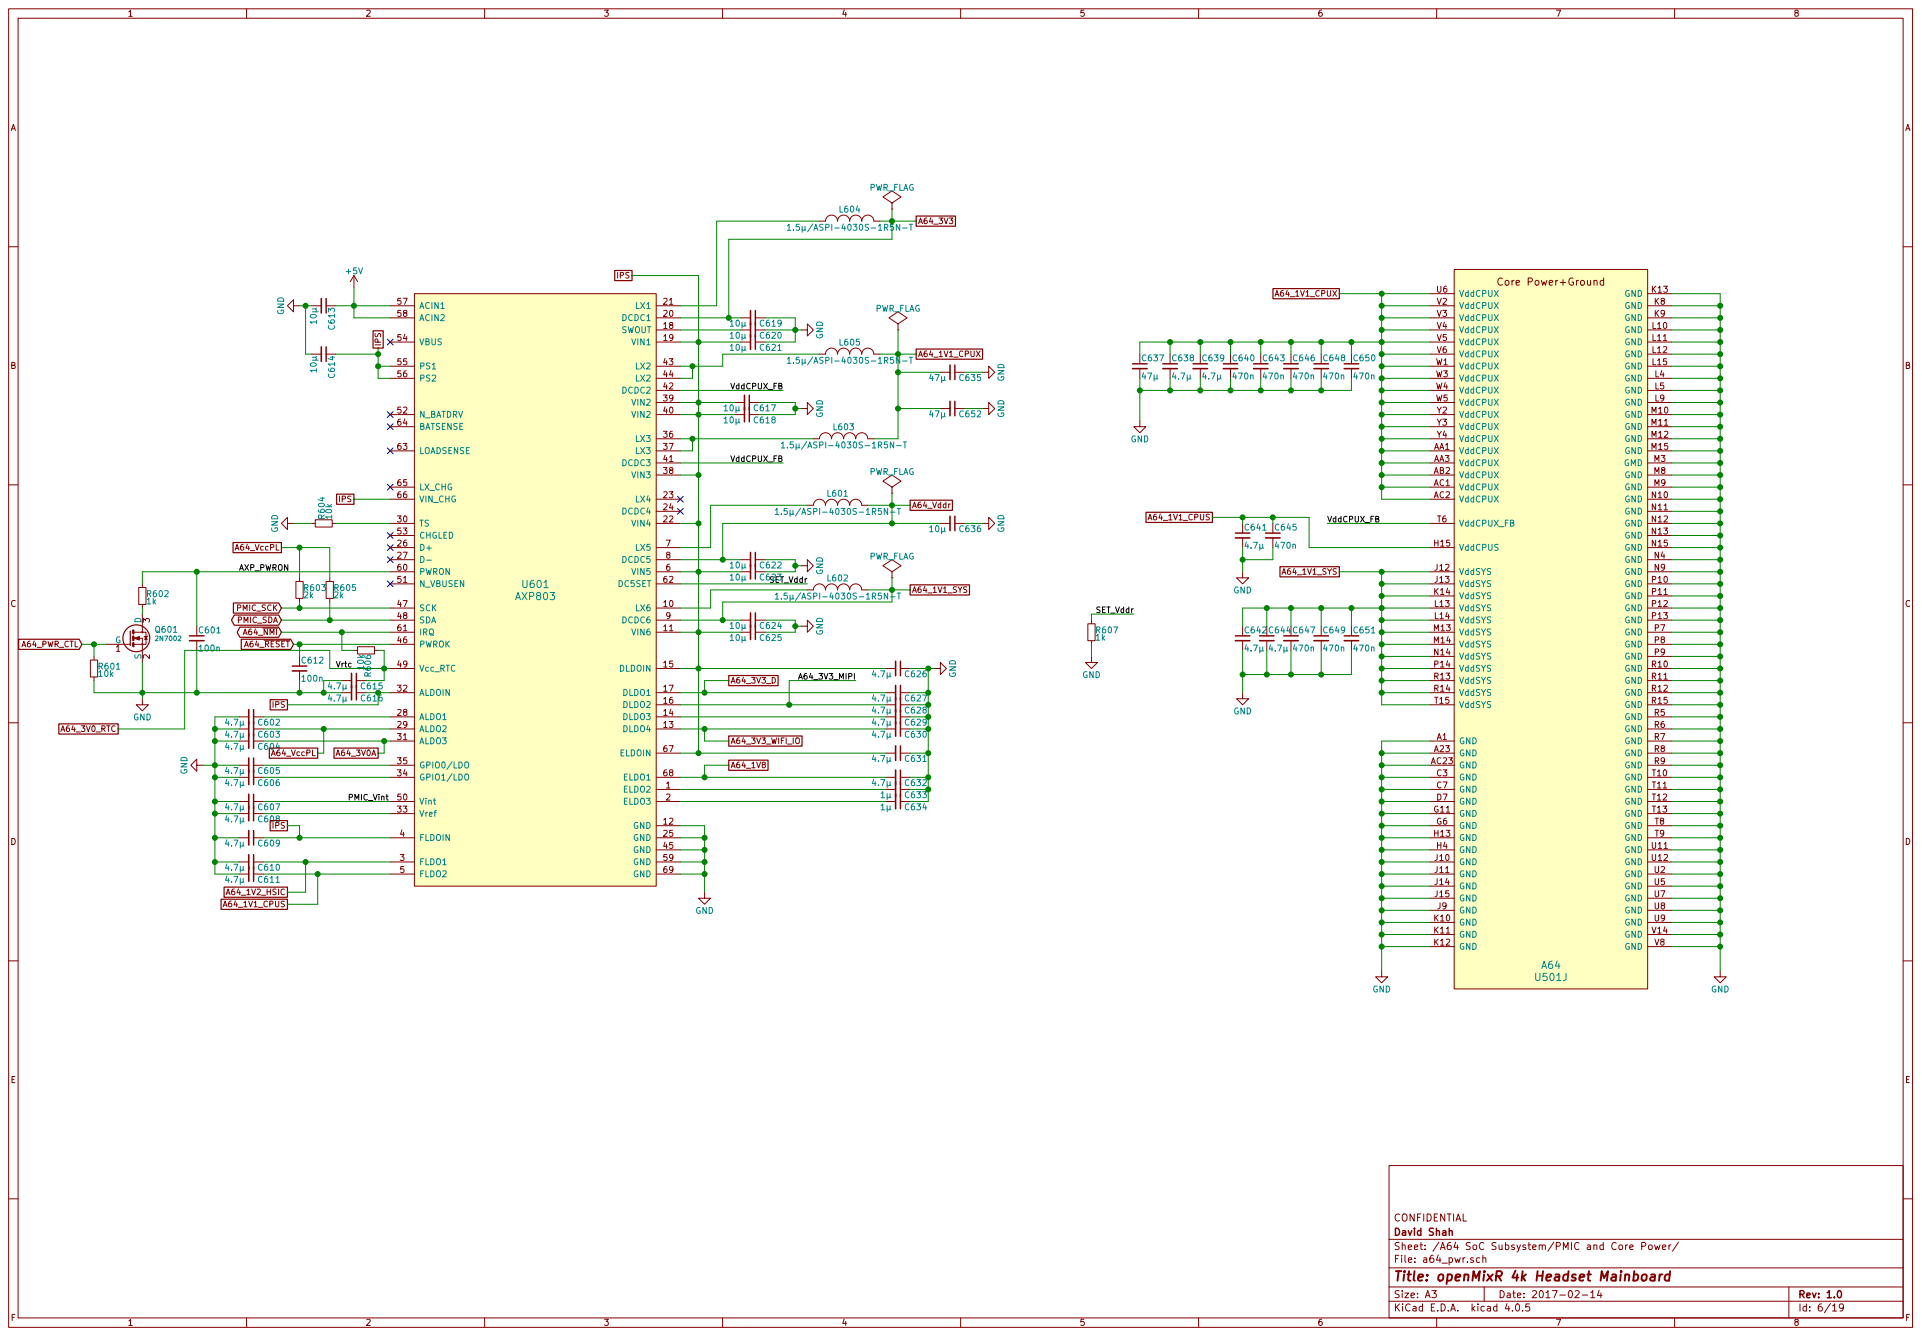
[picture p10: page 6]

Sheet: /A64 SoC Subsystem/PMIC and Core Power/ David Shah CONFIDENTIAL

File: a64_pwr.sch
Id: 6/19 Title: openMixR 4k Headset Mainboard

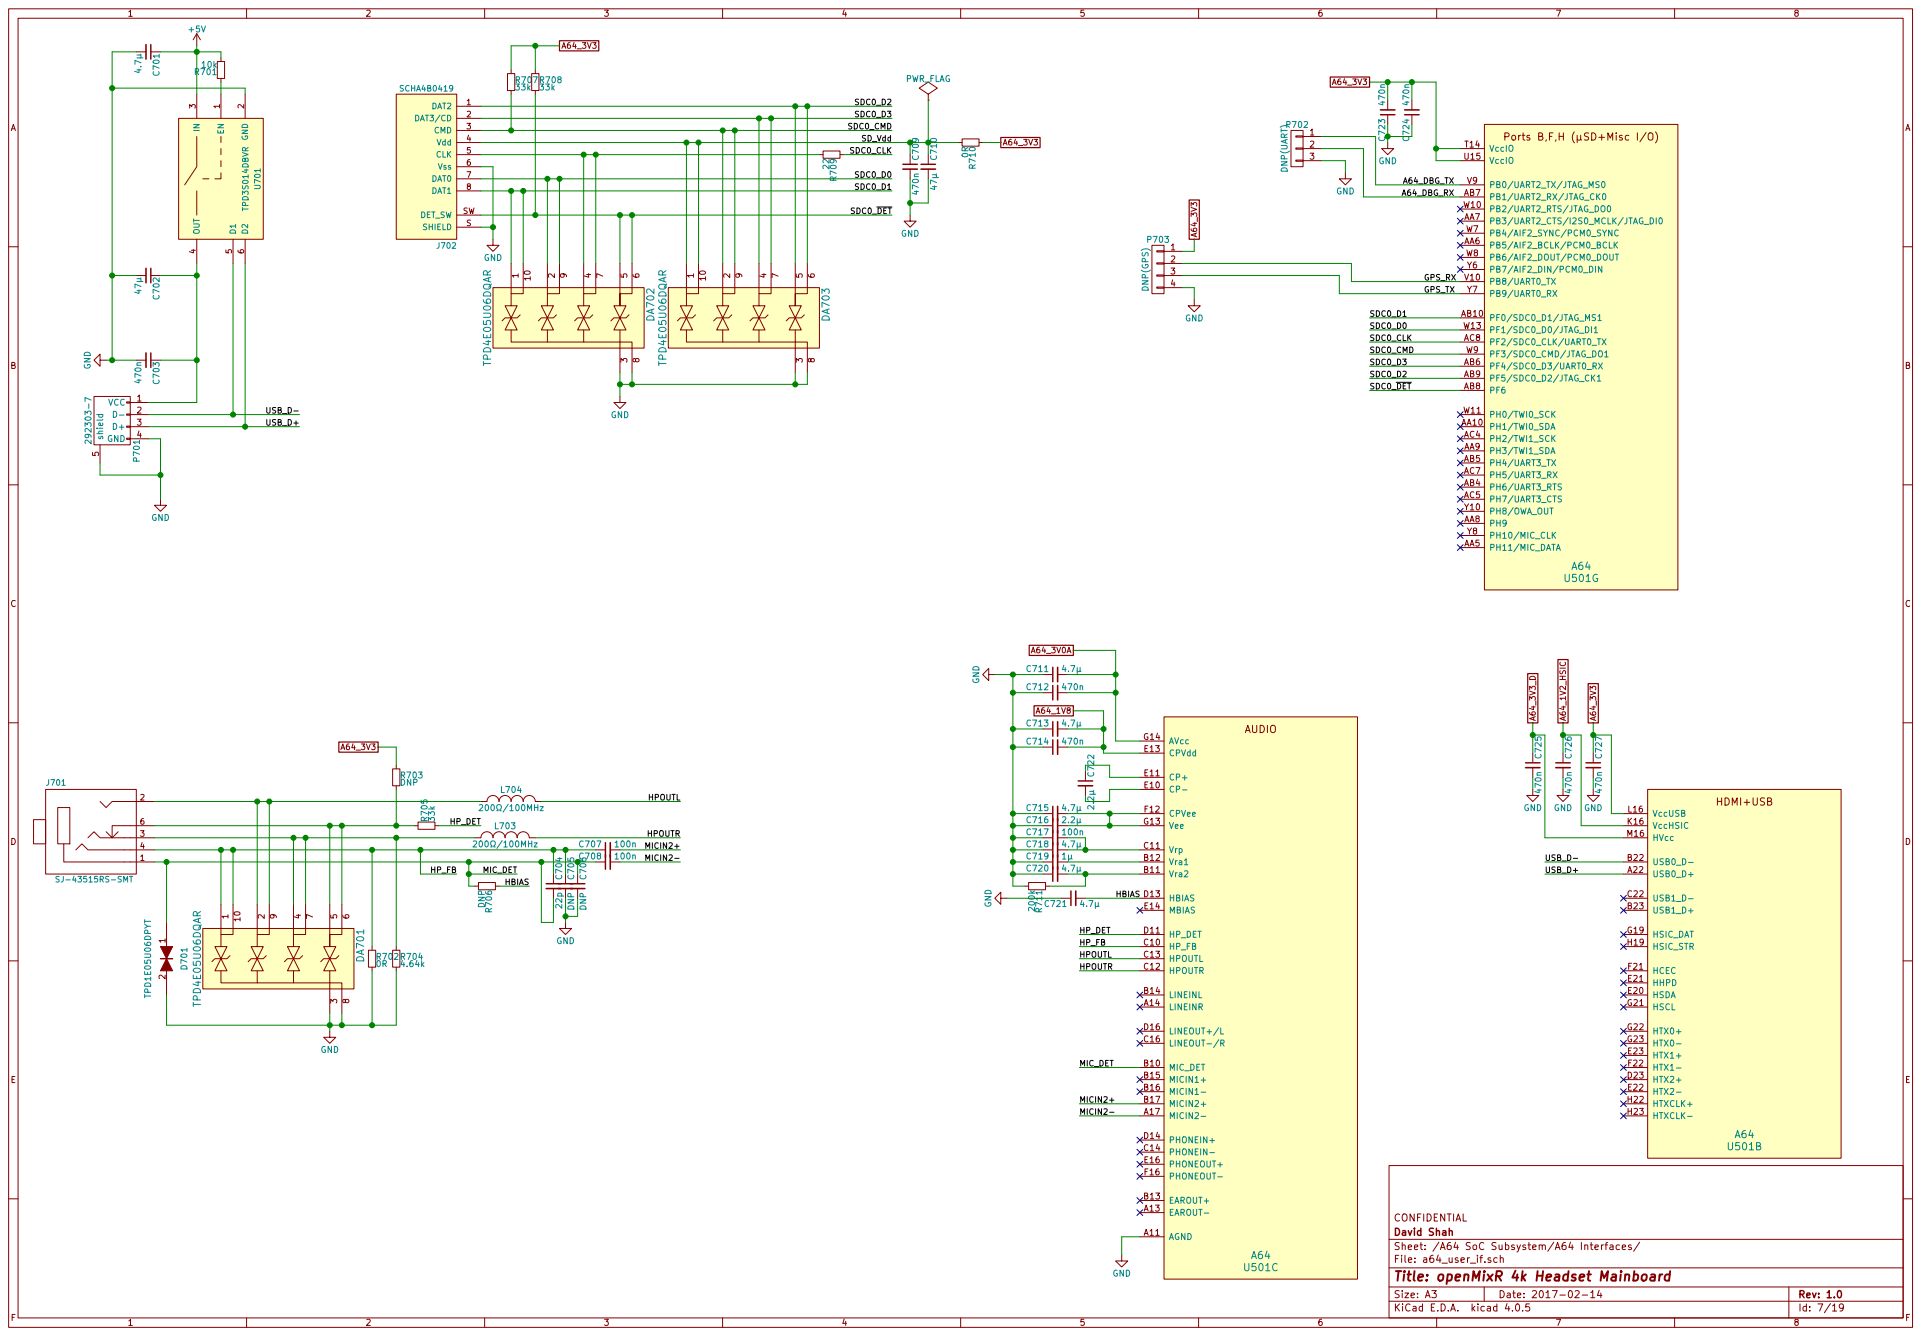
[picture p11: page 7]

File: a64_user_if.sch
Id: 7/19 Title: openMixR 4k Headset Mainboard

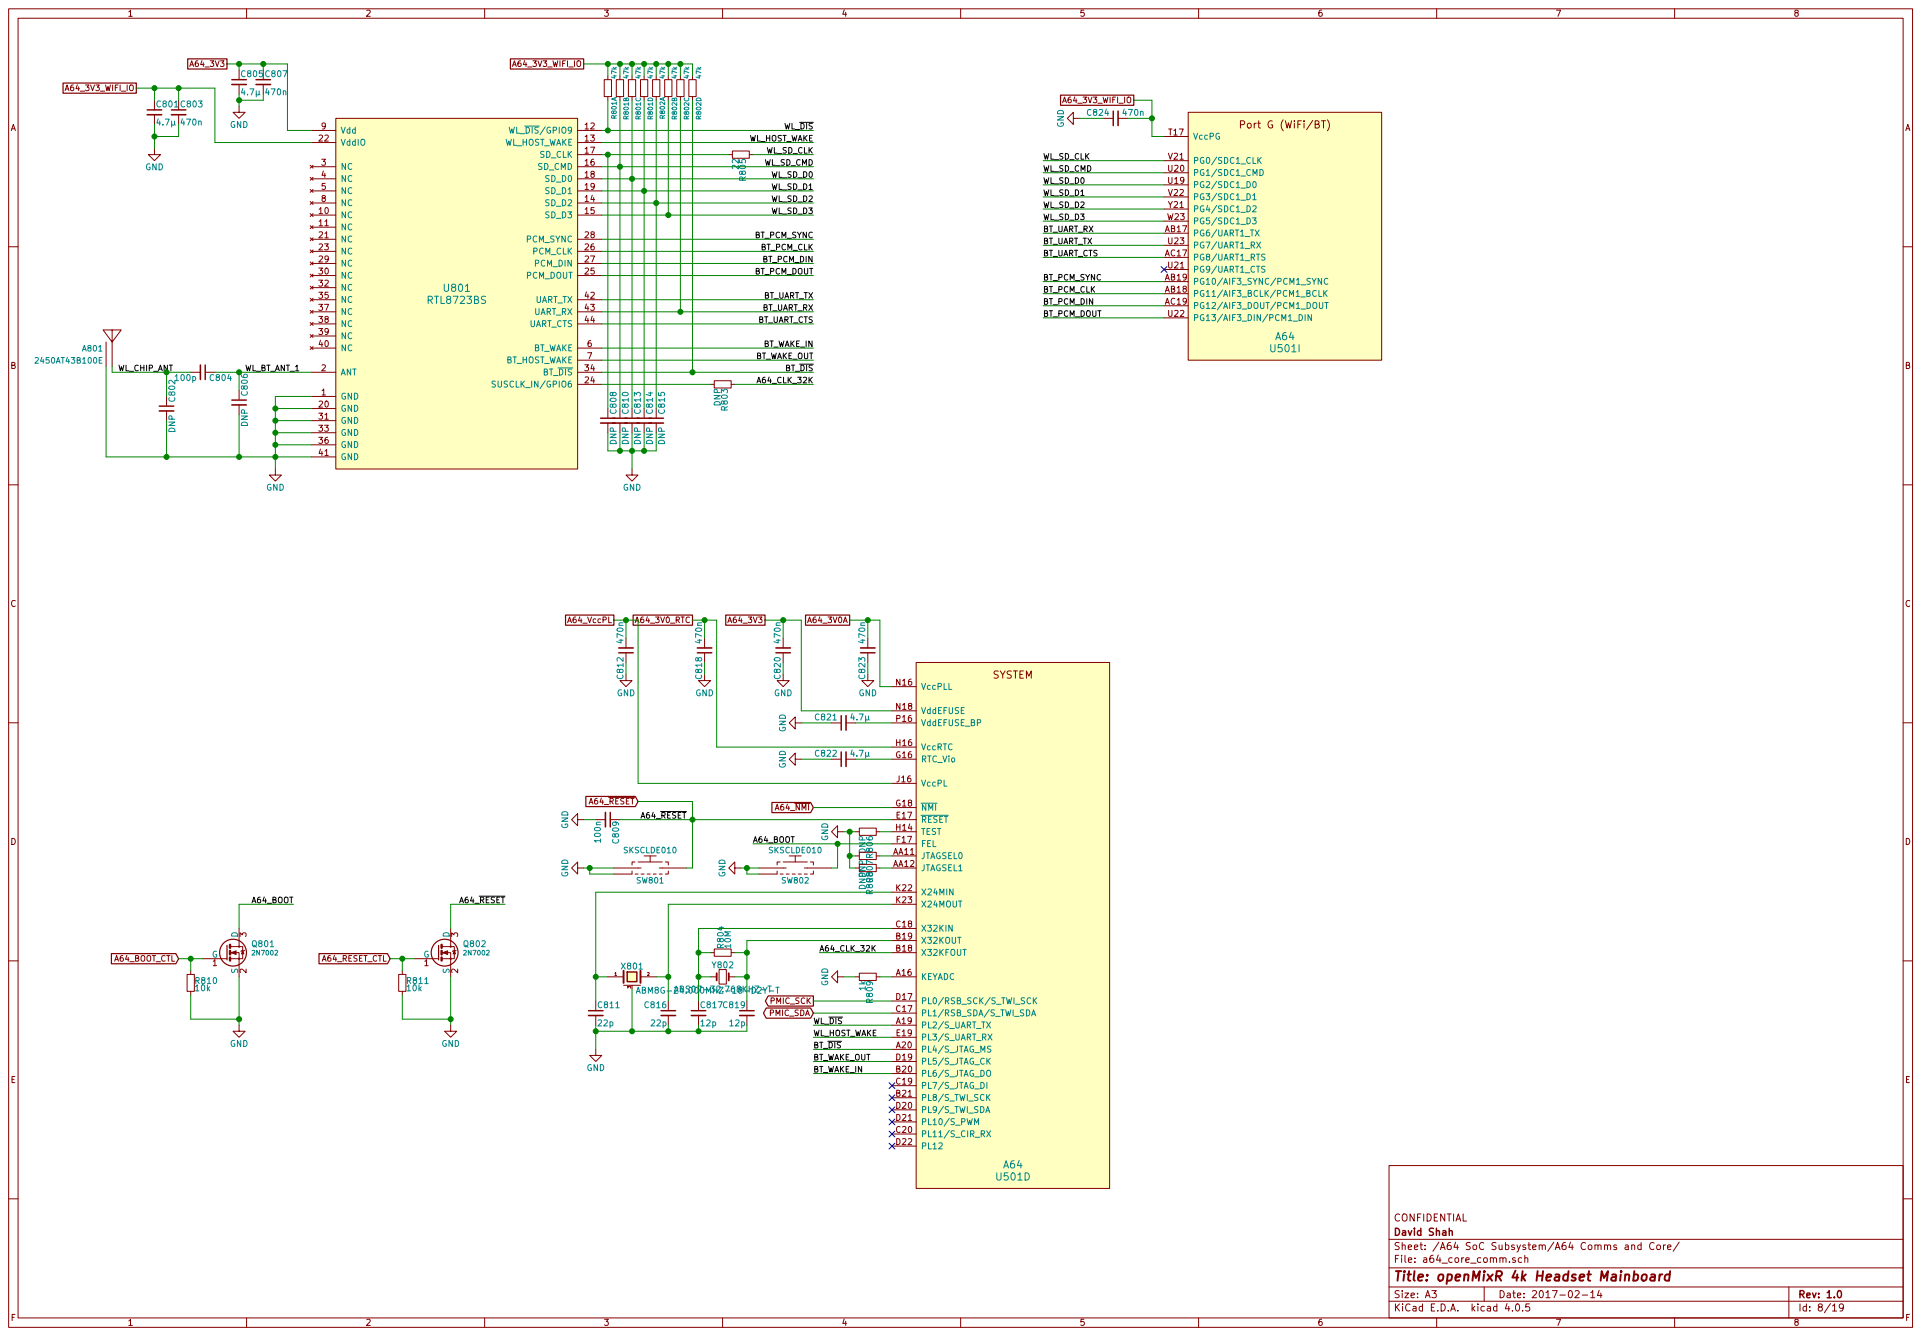
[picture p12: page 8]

Sheet: /A64 SoC Subsystem/A64 Comms and Core/ David Shah CONFIDENTIAL

File: a64_core_comm.sch
Id: 8/19 Title: openMixR 4k Headset Mainboard

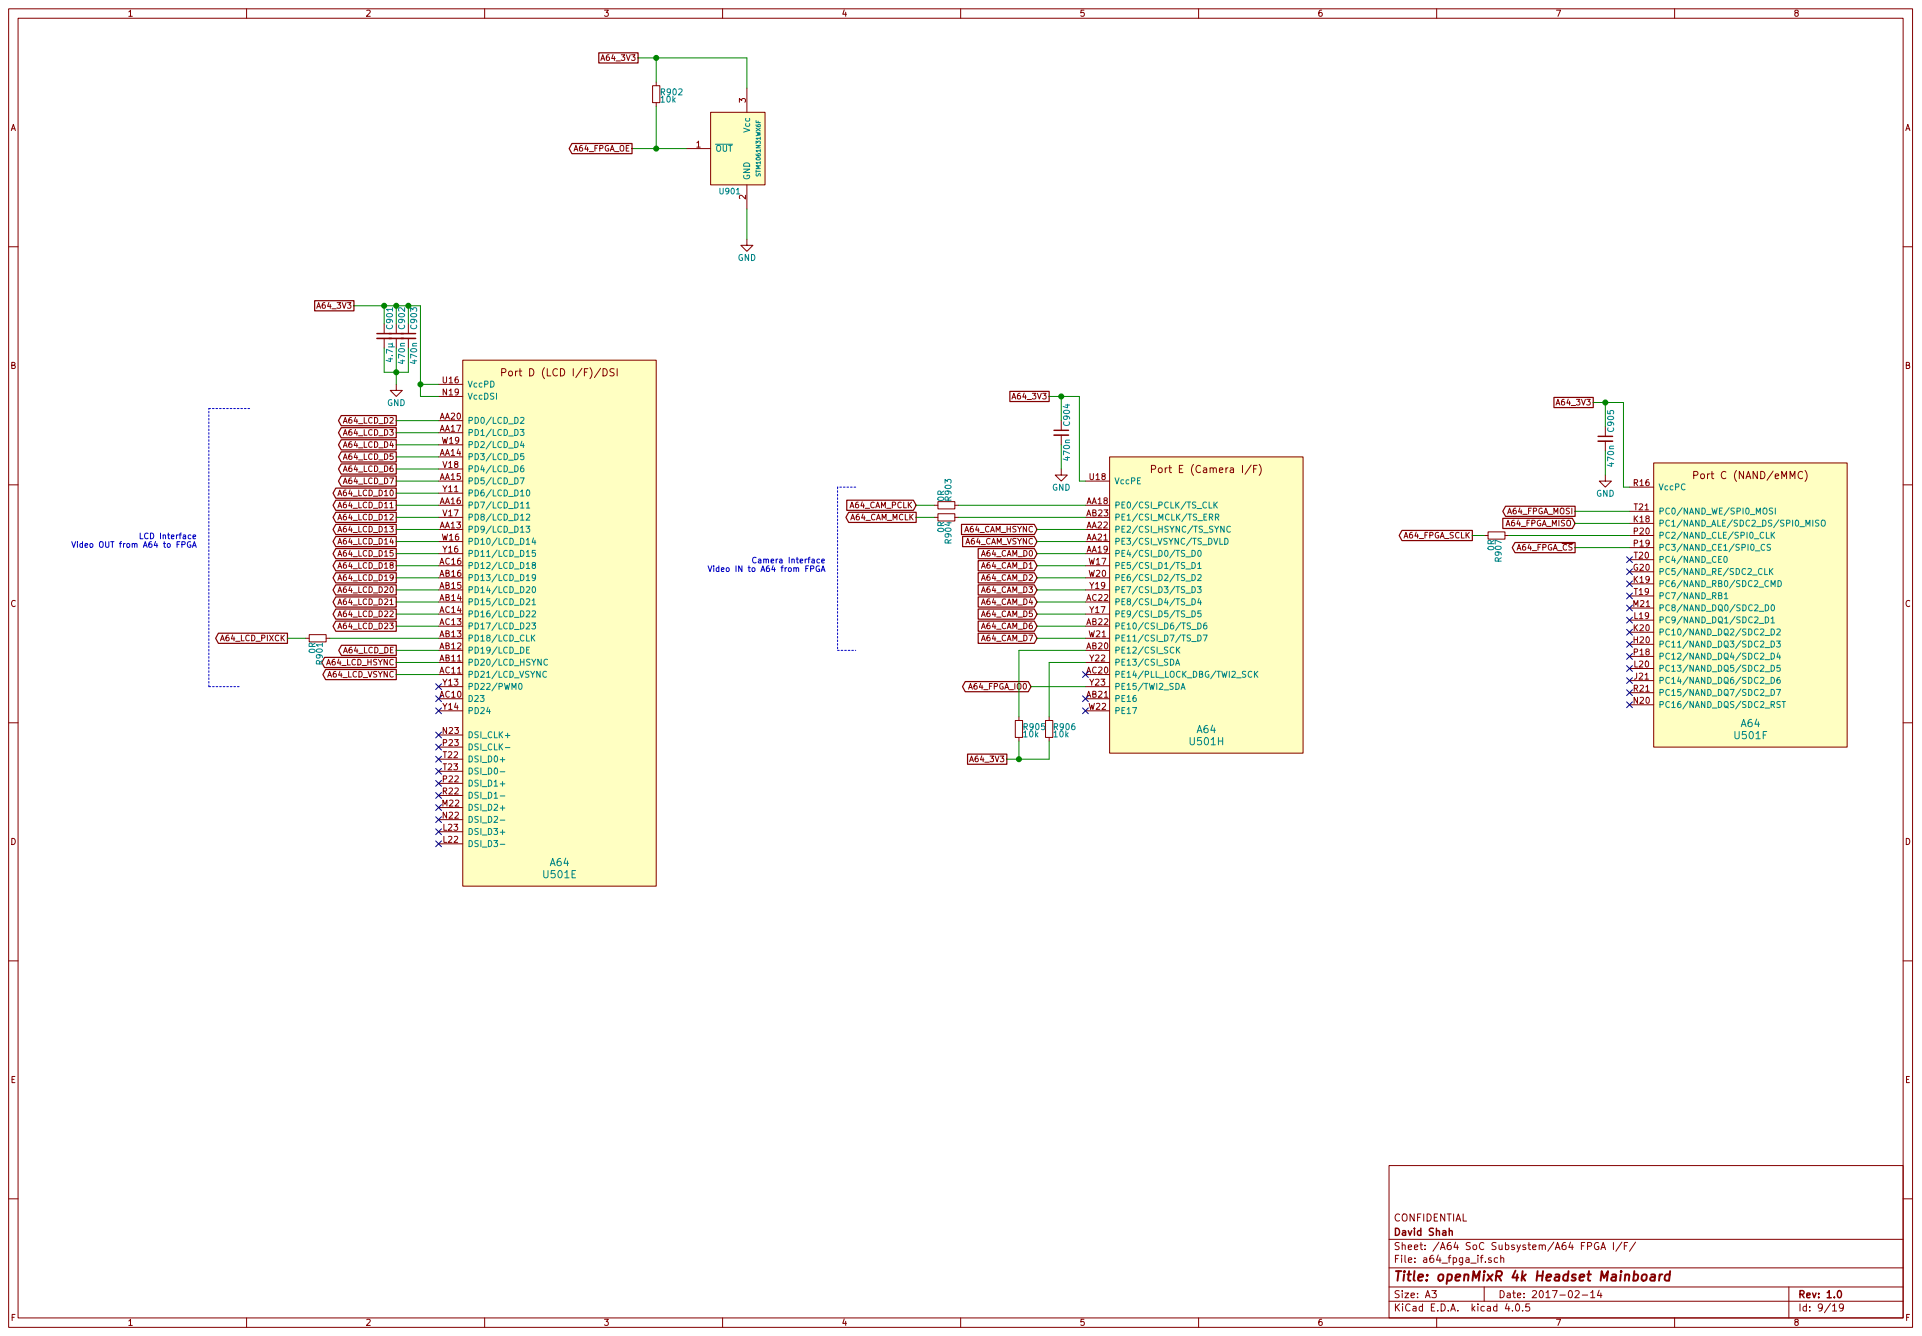
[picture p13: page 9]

LCD Interface Video OUT from A64 to FPGA

Sheet: /A64 SoC Subsystem/A64 FPGA I/F/ David Shah CONFIDENTIAL

File: a64_fpga_if.sch
Id: 9/19 Title: openMixR 4k Headset Mainboard

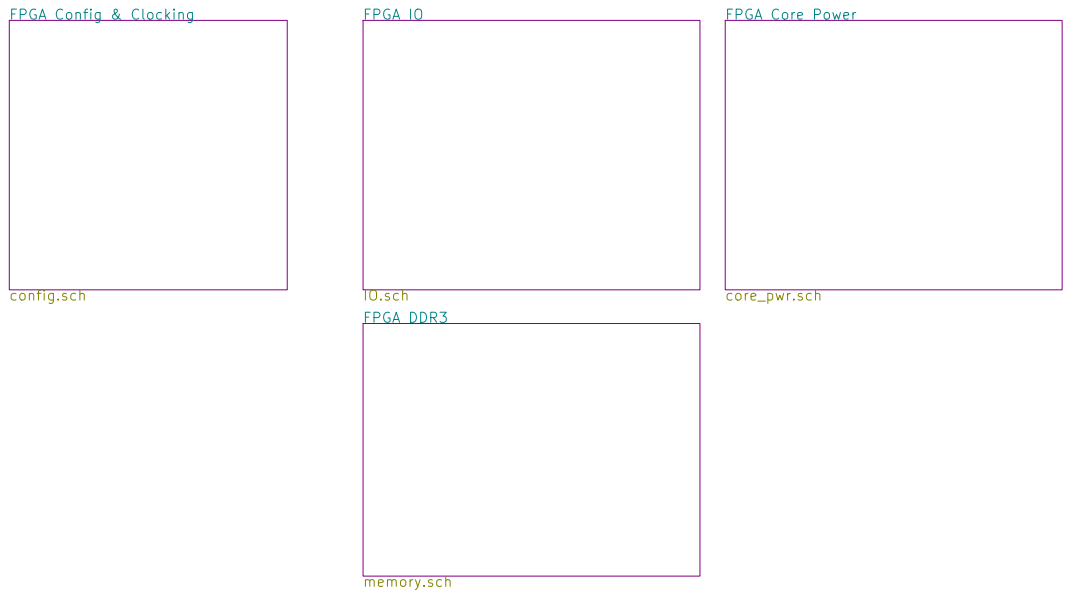
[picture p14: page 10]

Sheet: /Artix-7 FPGA Subsystem/ David Shah CONFIDENTIAL

File: fpgasys.sch
Id: 10/19 Title: openMixR 4k Headset Mainboard

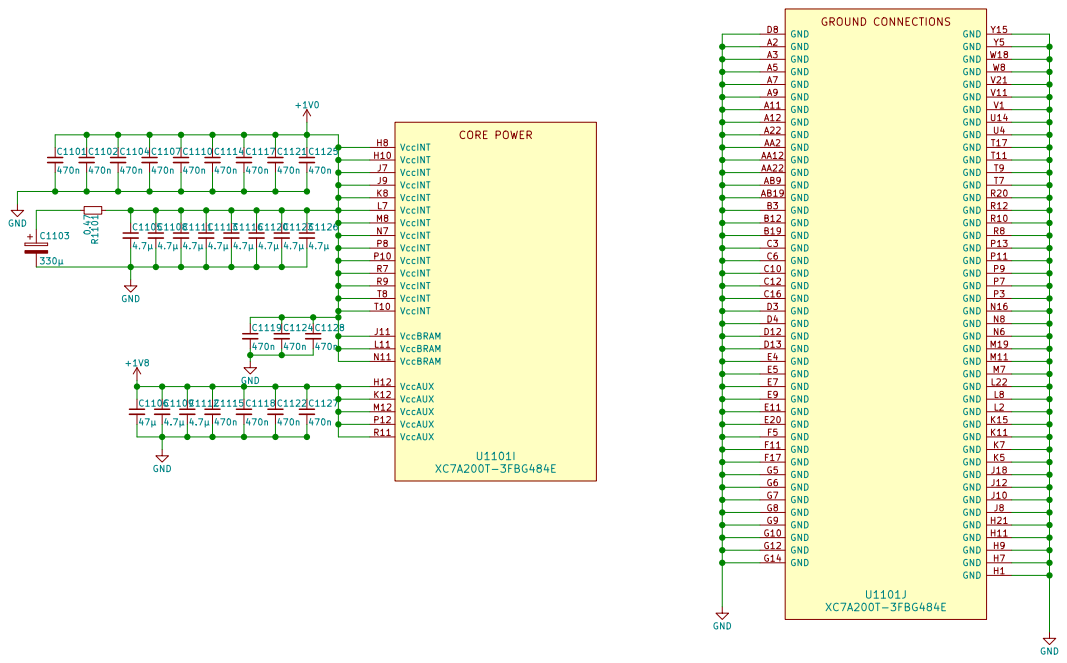
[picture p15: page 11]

Sheet: /Artix-7 FPGA Subsystem/FPGA Core Power/ David Shah CONFIDENTIAL

File: core_pwr.sch
Id: 11/19 Title: openMixR 4k Headset Mainboard


Sheet: /Artix-7 FPGA Subsystem/FPGA DDR3/ David Shah CONFIDENTIAL

File: memory.sch
Id: 12/19 Title: openMixR 4k Headset Mainboard


File: IO.sch Sheet: /Artix-7 FPGA Subsystem/FPGA IO/ David Shah CONFIDENTIAL

Id: 13/19 Title: openMixR 4k Headset Mainboard


Sheet: /Artix-7 FPGA Subsystem/FPGA Config & Clocking/ David Shah CONFIDENTIAL

File: config.sch
Id: 14/19 Title: openMixR 4k Headset Mainboard


47µ VccAUX, IO and Misc Devices 1.8V at 5A

4.7µ Vcc10_GTP GTP Core Supply 1.0V at 0.5A Camera Core and GTP Term
1µ/VLP8040T-1R0 C1512

Sheet: /Voltage Regulators and Power Management/ David Shah CONFIDENTIAL

File: vreg.sch
Id: 15/19 Title: openMixR 4k Headset Mainboard


33k Mode: direct PWM, analog <25%

Id: 16/19 Title: openMixR 4k Headset Mainboard


File: dsi_level_conv.sch Sheet: /LCD/DSI0 Level Converter/ David Shah CONFIDENTIAL R1702 120 120 R1703 R170122 22R1704 R1721

Id: 17/19 Title: openMixR 4k Headset Mainboard


File: dsi_level_conv.sch Sheet: /LCD/DSI1 Level Converter/ David Shah CONFIDENTIAL R1802 120 120 R1803 R180122 22R1804 R1821

Id: 18/19 Title: openMixR 4k Headset Mainboard


File: sensors.sch Sheet: /Sensors and UI/ David Shah CONFIDENTIAL

Id: 19/19 Title: openMixR 4k Headset Mainboard


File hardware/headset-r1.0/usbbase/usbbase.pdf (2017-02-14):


Id: 1/1 Title: USB-C Base



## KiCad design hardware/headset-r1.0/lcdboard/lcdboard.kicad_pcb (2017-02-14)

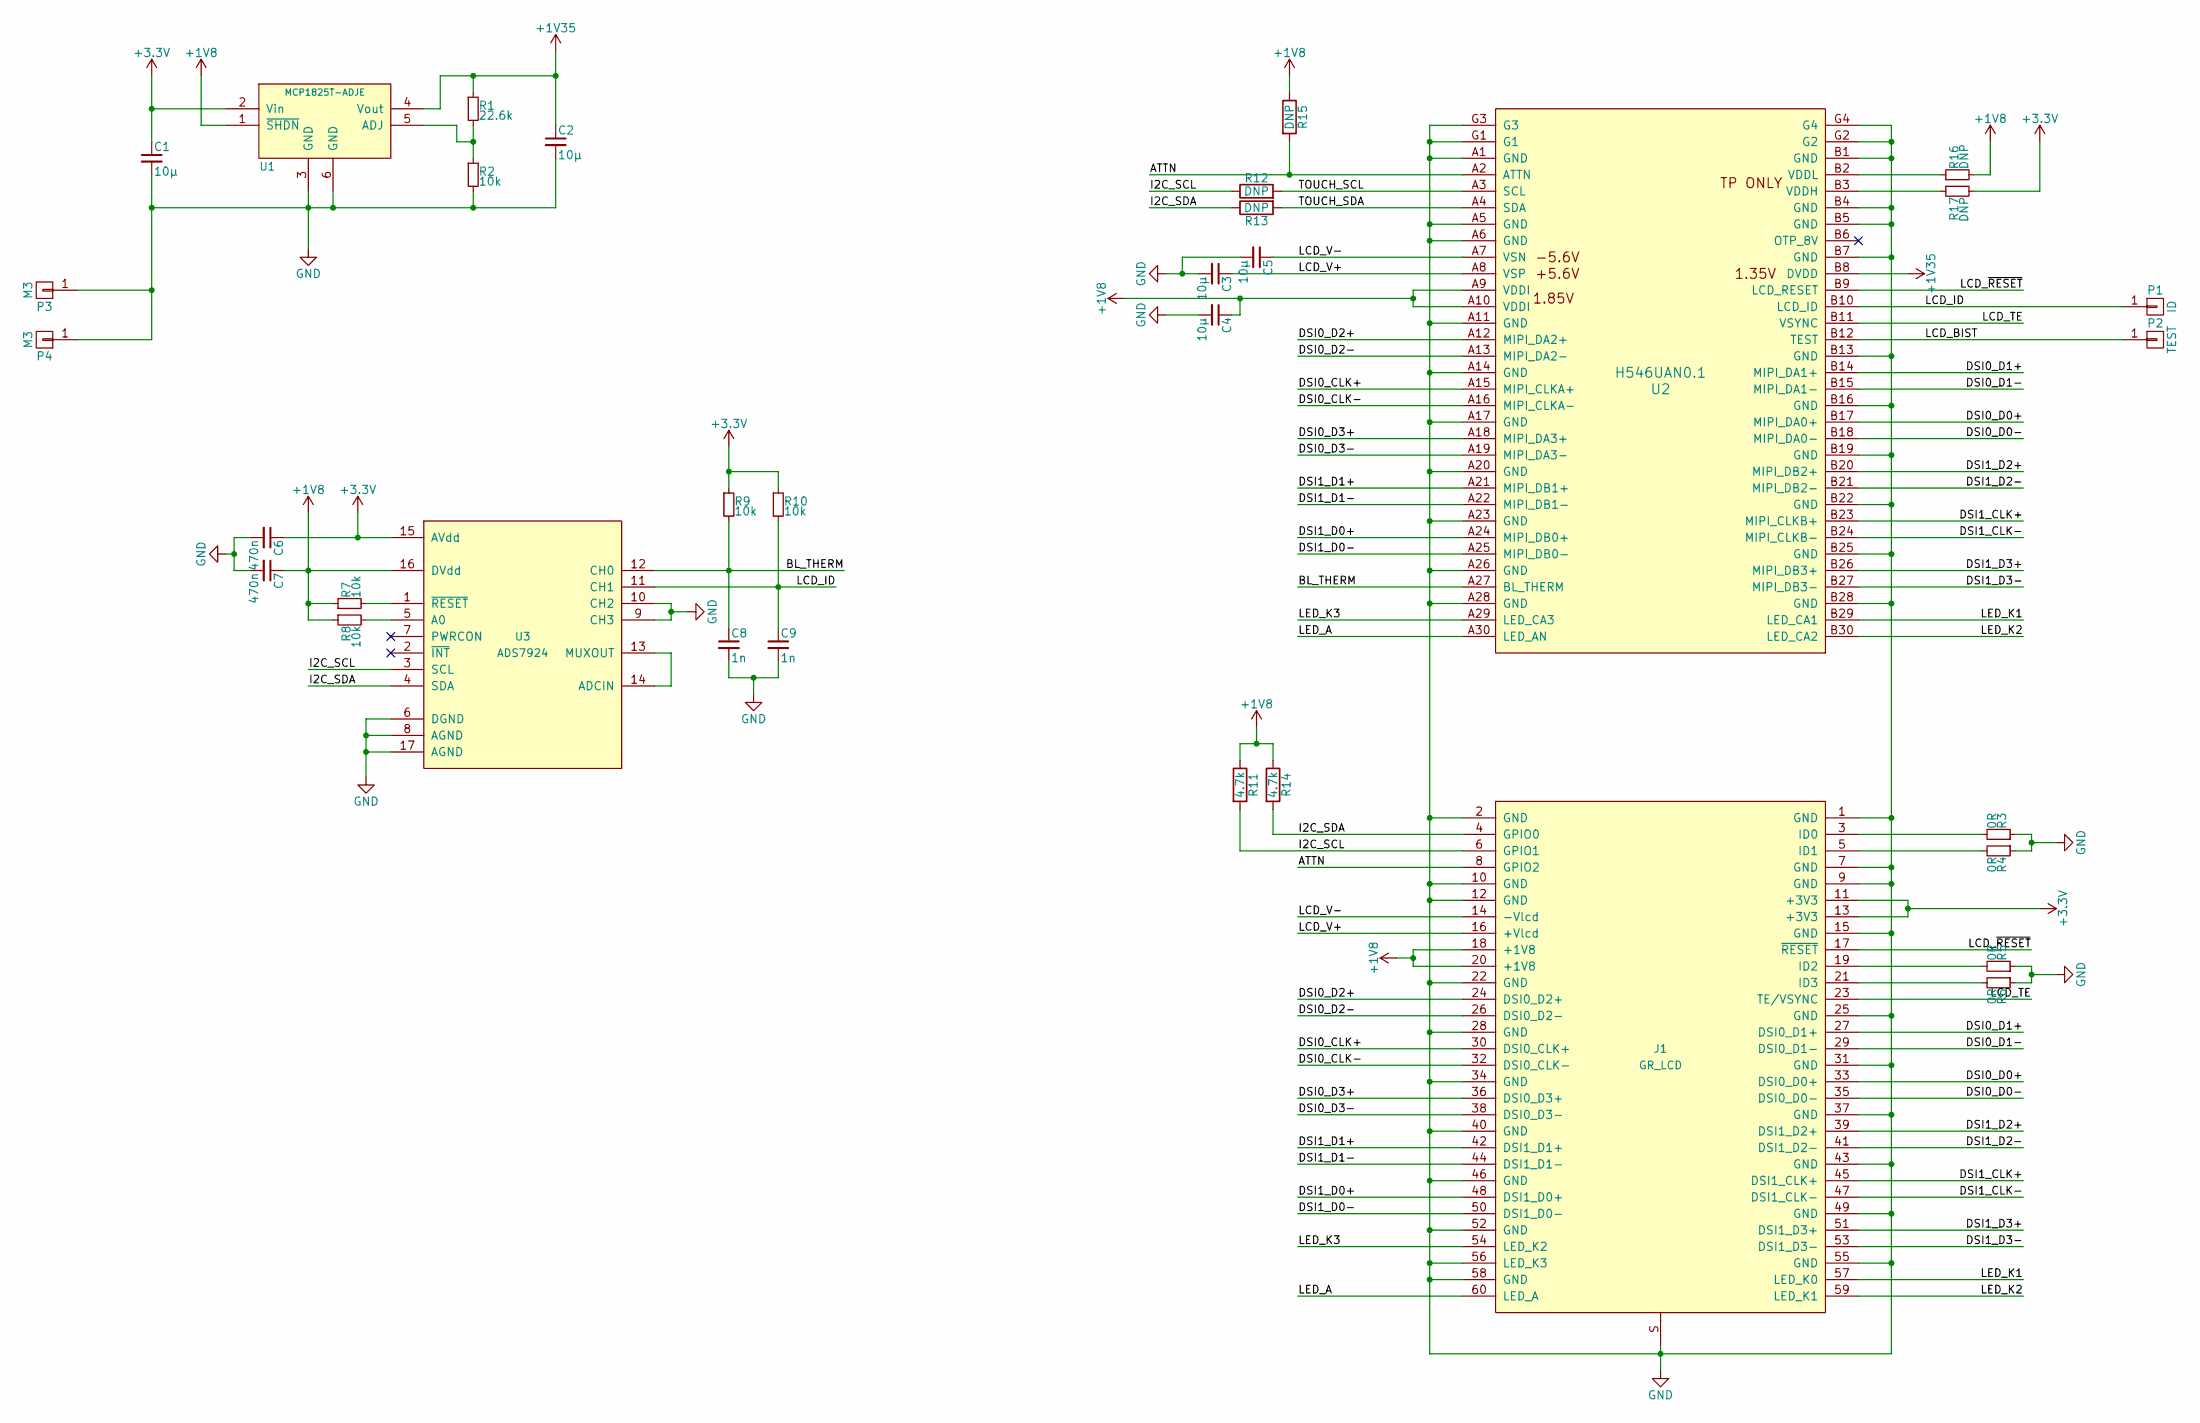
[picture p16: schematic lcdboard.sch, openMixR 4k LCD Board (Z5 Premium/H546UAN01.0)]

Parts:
C1, C2, C3, C4, C5: 10µ; C_0805
C6, C7: 470n; C_0402
C8, C9: 1n; C_0402
J1: GR_LCD; DF17(2.0)-60DP-0.5V(57)
P1: ID; Measurement_Point_Square-SMD-Pad_Big
P2: TEST; Measurement_Point_Square-SMD-Pad_Big
P3, P4: M3; M3_HOLE
R1: 22.6k; R_0402
R2, R7, R8, R9, R10: 10k; R_0402
R3, R4, R5, R6: 0R; R_0402
R11, R14: 4.7k; R_0402
R12, R13, R15, R16, R17: DNP; R_0402
U1: MCP1825T-ADJE; SOT-223-6
U2: H546UAN0.1; 60pin-0.35mm
U3: ADS7924; QFN-16-1EP_3x3mm_Pitch0.5mm

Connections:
+1V8: C4.1, C7.1, J1.18 (+1V8), J1.20 (+1V8), R7.1, R8.1, R11.1, R14.1, R15.1, R16.2, U1.1 (~SHDN), U2.A9 (VDDI), U2.A10 (VDDI), U3.16 (DVdd)
+1V35: C2.1, R1.1, U1.4 (Vout), U2.B8 (DVDD)
+3V3: C1.1, C6.1, J1.11 (+3V3), J1.13 (+3V3), R9.1, R10.1, R17.2, U1.2 (Vin), U3.15 (AVdd)
/ATTN: J1.8 (GPIO2), R15.2, U2.A2 (ATTN)
/BL_THERM: C8.1, R9.2, U2.A27 (BL_THERM), U3.12 (CH0)
/DSI0_CLK+: J1.30 (DSI0_CLK+), U2.A15 (MIPI_CLKA+)
/DSI0_CLK-: J1.32 (DSI0_CLK-), U2.A16 (MIPI_CLKA-)
/DSI0_D0+: J1.33 (DSI0_D0+), U2.B17 (MIPI_DA0+)
/DSI0_D0-: J1.35 (DSI0_D0-), U2.B18 (MIPI_DA0-)
/DSI0_D1+: J1.27 (DSI0_D1+), U2.B14 (MIPI_DA1+)
/DSI0_D1-: J1.29 (DSI0_D1-), U2.B15 (MIPI_DA1-)
/DSI0_D2+: J1.24 (DSI0_D2+), U2.A12 (MIPI_DA2+)
/DSI0_D2-: J1.26 (DSI0_D2-), U2.A13 (MIPI_DA2-)
/DSI0_D3+: J1.36 (DSI0_D3+), U2.A18 (MIPI_DA3+)
/DSI0_D3-: J1.38 (DSI0_D3-), U2.A19 (MIPI_DA3-)
/DSI1_CLK+: J1.45 (DSI1_CLK+), U2.B23 (MIPI_CLKB+)
/DSI1_CLK-: J1.47 (DSI1_CLK-), U2.B24 (MIPI_CLKB-)
/DSI1_D0+: J1.48 (DSI1_D0+), U2.A24 (MIPI_DB0+)
/DSI1_D0-: J1.50 (DSI1_D0-), U2.A25 (MIPI_DB0-)
/DSI1_D1+: J1.42 (DSI1_D1+), U2.A21 (MIPI_DB1+)
/DSI1_D1-: J1.44 (DSI1_D1-), U2.A22 (MIPI_DB1-)
/DSI1_D2+: J1.39 (DSI1_D2+), U2.B20 (MIPI_DB2+)
/DSI1_D2-: J1.41 (DSI1_D2-), U2.B21 (MIPI_DB2-)
/DSI1_D3+: J1.51 (DSI1_D3+), U2.B26 (MIPI_DB3+)
/DSI1_D3-: J1.53 (DSI1_D3-), U2.B27 (MIPI_DB3-)
/I2C_SCL: J1.6 (GPIO1), R11.2, R12.1, U3.3 (SCL)
/I2C_SDA: J1.4 (GPIO0), R13.1, R14.2, U3.4 (SDA)
/LCD_BIST: P2.1, U2.B12 (TEST)
/LCD_ID: C9.1, P1.1, R10.2, U2.B10 (LCD_ID), U3.11 (CH1)
/LCD_TE: J1.23 (TE/VSYNC), U2.B11 (VSYNC)
/LCD_V+: C3.1, J1.16 (+Vlcd), U2.A8 (VSP)
/LCD_V-: C5.1, J1.14 (-Vlcd), U2.A7 (VSN)
/LCD_~RESET: J1.17 (~RESET), U2.B9 (LCD_RESET)
/LED_A: J1.60 (LED_A), U2.A30 (LED_AN)
/LED_K1: J1.57 (LED_K0), U2.B29 (LED_CA1)
/LED_K2: J1.59 (LED_K1), U2.B30 (LED_CA2)
/LED_K3: J1.54 (LED_K2), U2.A29 (LED_CA3)
/TOUCH_SCL: R12.2, U2.A3 (SCL)
/TOUCH_SDA: R13.2, U2.A4 (SDA)
GND: C1.2, C2.2, C3.2, C4.2, C5.2, C6.2, C7.2, C8.2, C9.2, J1.1 (GND), J1.2 (GND), J1.7 (GND), J1.9 (GND), J1.10 (GND), J1.12 (GND), J1.15 (GND), J1.22 (GND), J1.25 (GND), J1.28 (GND), J1.31 (GND), J1.34 (GND), J1.37 (GND), J1.40 (GND), J1.43 (GND), J1.46 (GND), J1.49 (GND), J1.52 (GND), J1.55 (GND), J1.56 (LED_K3), J1.58 (GND), J1.S, P3.1, P4.1, R2.2, R3.1, R4.1, R5.1, R6.1, U1.3 (GND), U1.6 (GND), U2.A1 (GND), U2.A5 (GND), U2.A6 (GND), U2.A11 (GND), U2.A14 (GND), U2.A17 (GND), U2.A20 (GND), U2.A23 (GND), U2.A26 (GND), U2.A28 (GND), U2.B1 (GND), U2.B4 (GND), U2.B5 (GND), U2.B7 (GND), U2.B13 (GND), U2.B16 (GND), U2.B19 (GND), U2.B22 (GND), U2.B25 (GND), U2.B28 (GND), U2.G1, U2.G2, U2.G3, U2.G4, U3.6 (DGND), U3.8 (AGND), U3.9 (CH3), U3.10 (CH2), U3.17 (AGND)
unnamed: J1.3 (ID0), R3.2
unnamed: J1.5 (ID1), R4.2
unnamed: J1.19 (ID2), R5.2
unnamed: J1.21 (ID3), R6.2
unnamed: R1.2, R2.1, U1.5 (ADJ)
unnamed: R7.2, U3.1 (~RESET)
unnamed: R8.2, U3.5 (A0)
unnamed: R16.1, U2.B2 (VDDL)
unnamed: R17.1, U2.B3 (VDDH)
unnamed: U3.13 (MUXOUT), U3.14 (ADCIN)

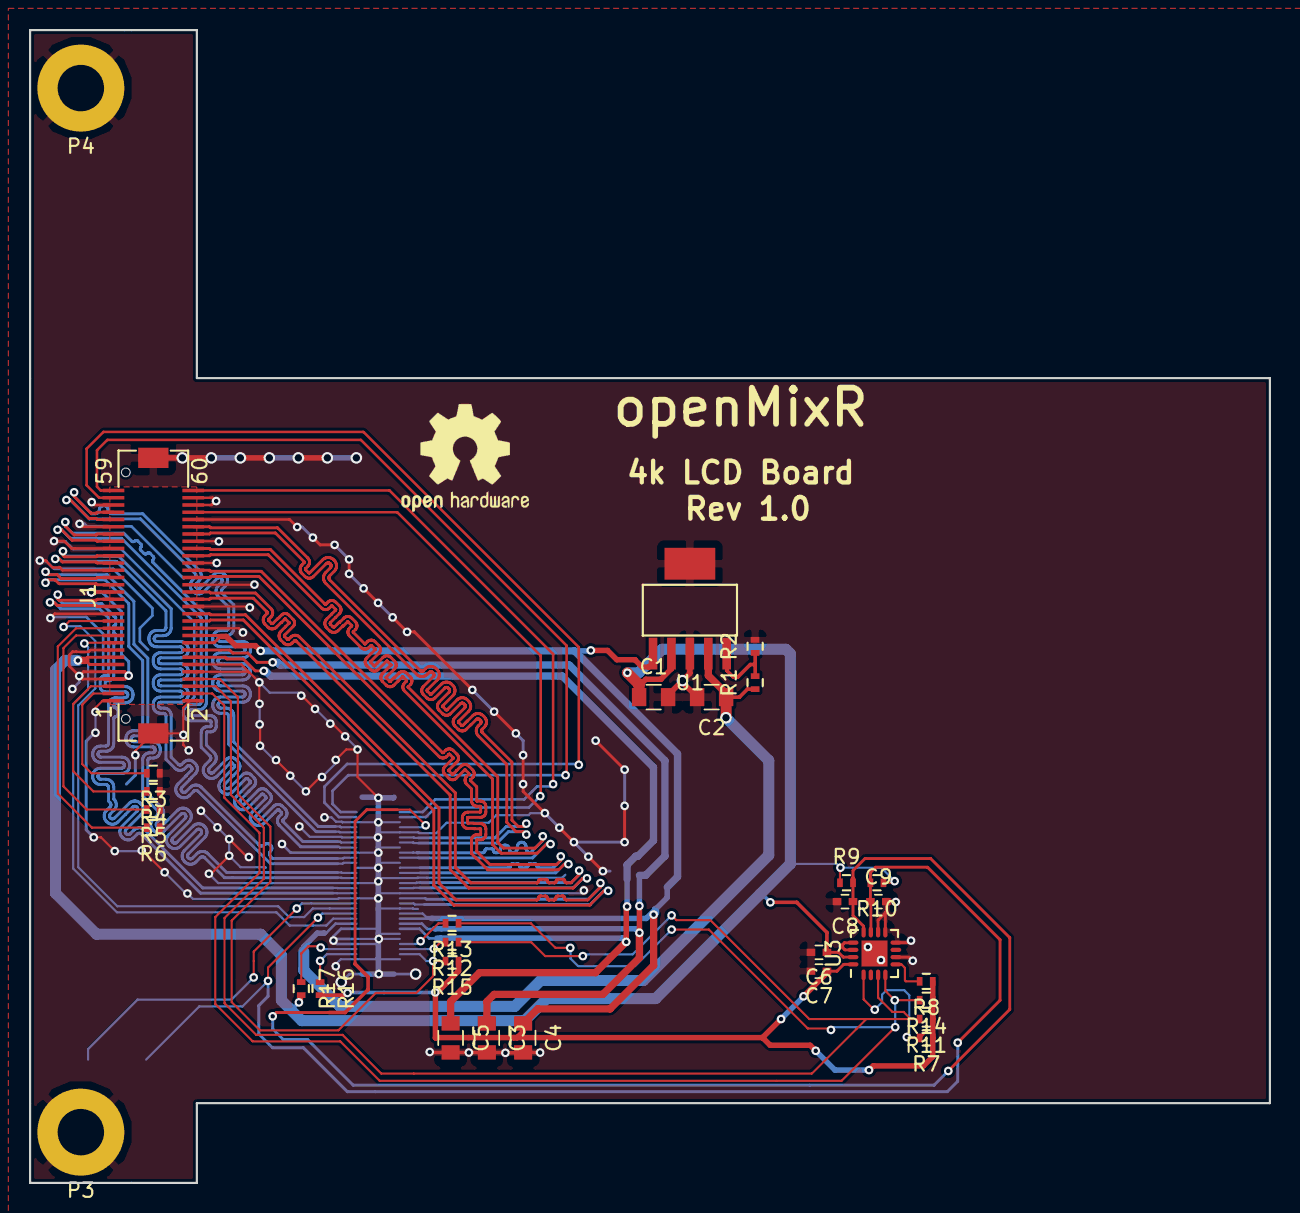
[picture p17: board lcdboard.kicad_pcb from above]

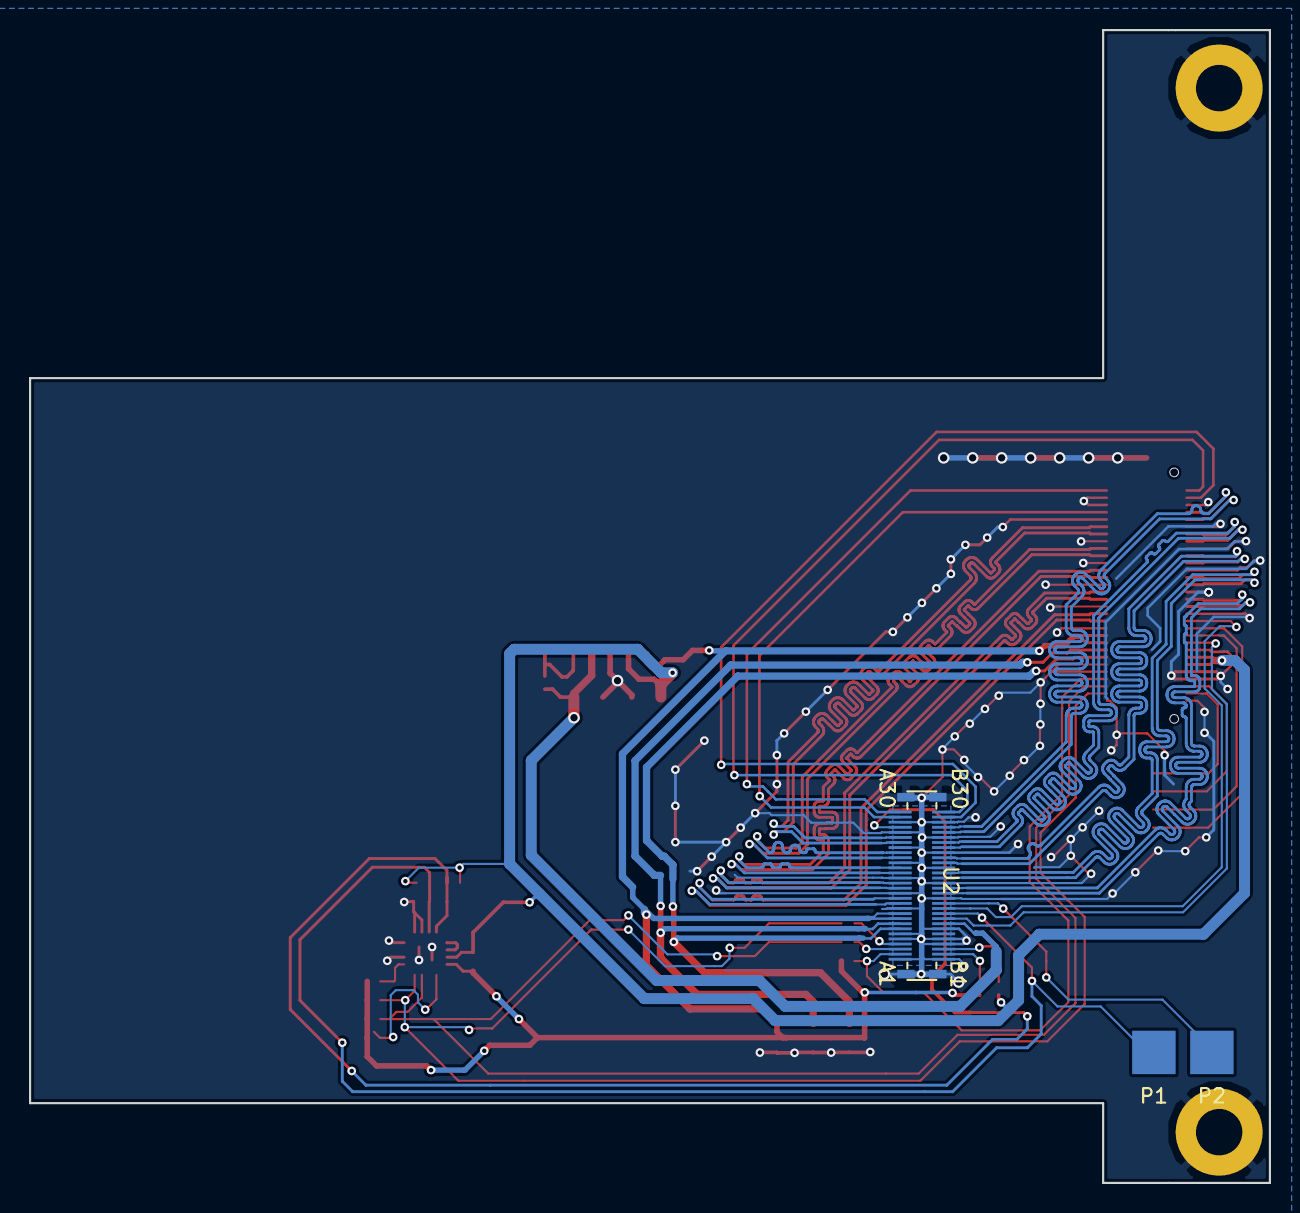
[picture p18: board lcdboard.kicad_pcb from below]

Board: 4 copper layers, 85.5 x 79.5 mm, 34 parts (3 on the bottom side), 50 nets.

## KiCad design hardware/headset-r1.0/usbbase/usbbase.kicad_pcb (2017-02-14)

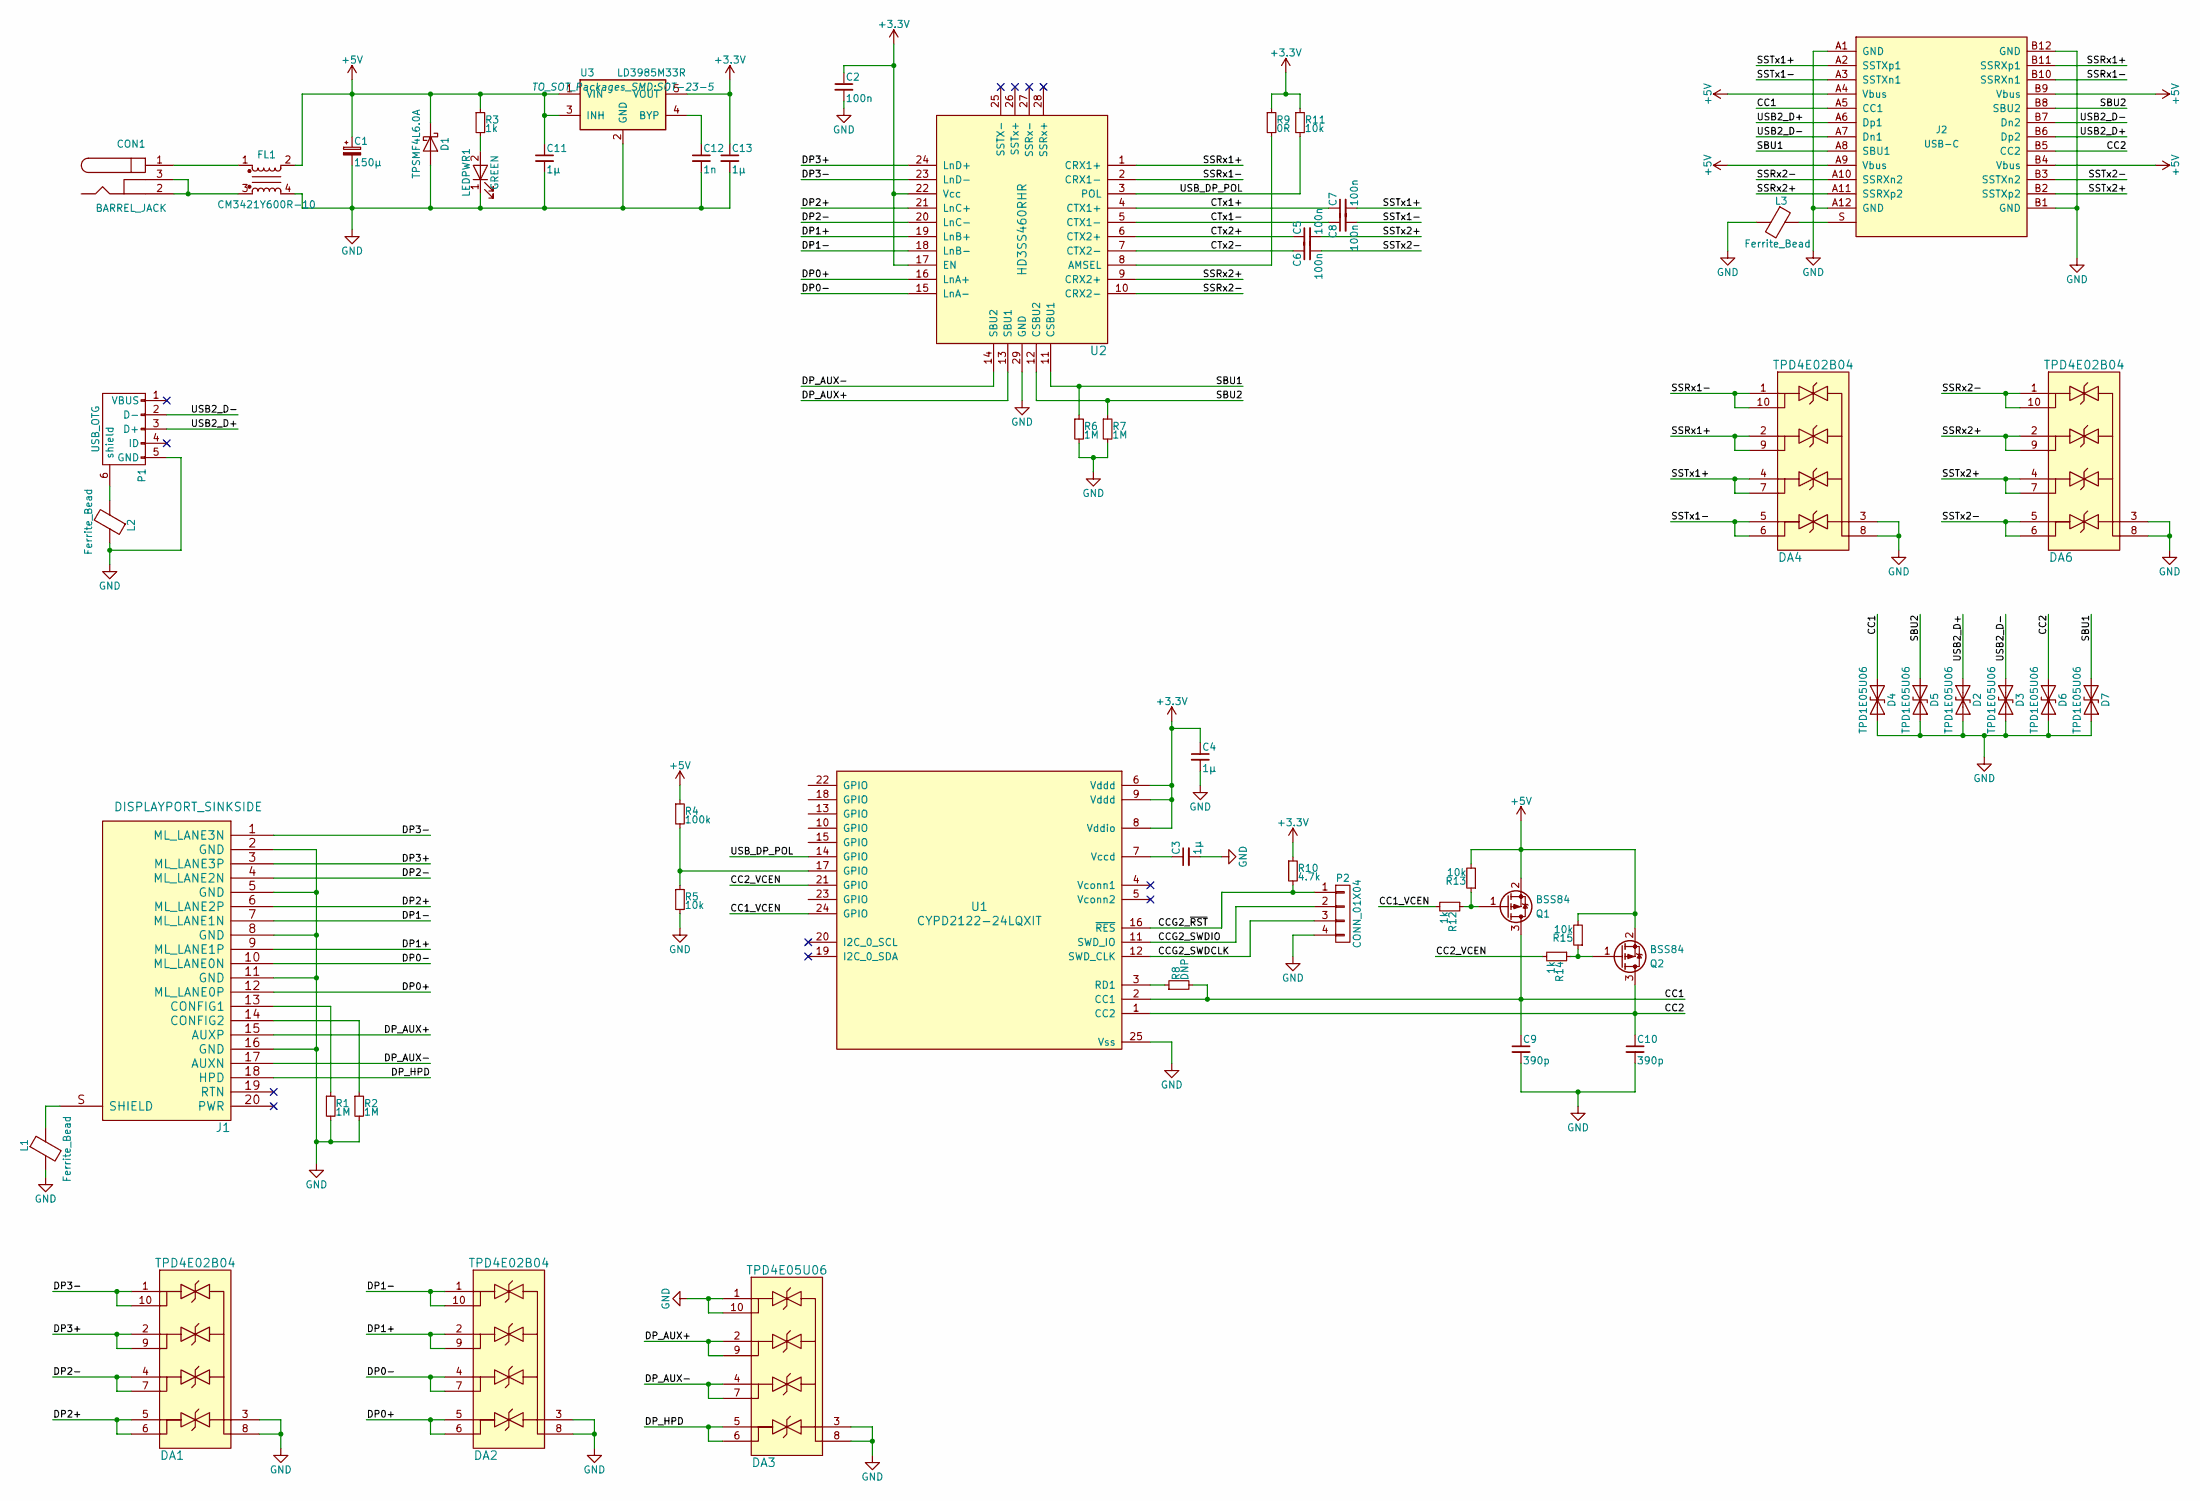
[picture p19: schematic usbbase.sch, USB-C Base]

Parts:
C1: 150µ; CP_Elec_6.3x5.8
C2, C5, C6, C7, C8: 100n; C_0402
C3, C4, C11, C13: 1µ; C_0603
C9, C10: 390p; C_0402
C12: 1n; C_0402
CON1: BARREL_JACK
D1: TPSMF4L6.0A; D_SOD-123
D2, D3, D4, D5, D6, D7: TPD1E05U06; X1SON2
DA1, DA2, DA4, DA6: TPD4E02B04; USON10
DA3: TPD4E05U06; USON10
FL1: CM3421Y600R-10
J1: DISPLAYPORT_SINKSIDE; 0472720024
J2: USB-C; USBC-12401548E4#2A
L1, L2, L3: Ferrite_Bead; R_0805
LEDPWR1: GREEN; LED_D3.0mm
P1: USB_OTG; USB_Micro-B
P2: CONN_01X04; Pin_Header_Straight_1x04_Pitch2.54mm
Q1, Q2: BSS84; SOT-23
R1, R2, R6, R7: 1M; R_0402
R3, R12, R14: 1k; R_0402
R4: 100k; R_0402
R5, R11, R13, R15: 10k; R_0402
R8: DNP; R_0402
R9: 0R; R_0402
R10: 4.7k; R_0402
U1: CYPD2122-24LQXIT; QFN-24-1EP_4x4mm_Pitch0.5mm
U2: HD3SS460RHR; WQFN28EP_5.5x3.5mm_Pitch0.5mm
U3: LD3985M33R; SOT-23-5

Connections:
+3V3: C2.1, C4.1, C13.1, R9.1, R10.1, R11.1, U1.6 (Vddd), U1.8 (Vddio), U1.9 (Vddd), U2.17 (EN), U2.22 (Vcc), U3.5 (VOUT)
+5V: C1.1, C11.1, D1.1 (K), FL1.2, J2.A4 (Vbus), J2.A9 (Vbus), J2.B4 (Vbus), J2.B9 (Vbus), Q1.2 (S), Q2.2 (S), R3.1, R4.1, R13.2, R15.2, U3.1 (VIN), U3.3 (INH)
/CC1: C9.1, D4.1 (A1), J2.A5 (CC1), Q1.3 (D), R8.2, U1.2 (CC1)
/CC1_VCEN: R12.2, U1.24 (GPIO)
/CC2: C10.1, D6.1 (A1), J2.B5 (CC2), Q2.3 (D), U1.1 (CC2)
/CC2_VCEN: R14.2, U1.21 (GPIO)
/CCG2_SWDCLK: P2.3, U1.12 (SWD_CLK)
/CCG2_SWDIO: P2.2, U1.11 (SWD_IO)
/CCG2_~RST: P2.1, R10.2, U1.16 (~RES)
/CTx1+: C7.1, U2.4 (CTX1+)
/CTx1-: C8.1, U2.5 (CTX1-)
/CTx2+: C5.1, U2.6 (CTX2+)
/CTx2-: C6.1, U2.7 (CTX2-)
/DP0+: DA2.5 (IO4), DA2.6, J1.12 (ML_LANE0P), U2.16 (LnA+)
/DP0-: DA2.4 (IO3), DA2.7, J1.10 (ML_LANE0N), U2.15 (LnA-)
/DP1+: DA2.2 (IO2), DA2.9, J1.9 (ML_LANE1P), U2.19 (LnB+)
/DP1-: DA2.1 (IO1), DA2.10, J1.7 (ML_LANE1N), U2.18 (LnB-)
/DP2+: DA1.5 (IO4), DA1.6, J1.6 (ML_LANE2P), U2.21 (LnC+)
/DP2-: DA1.4 (IO3), DA1.7, J1.4 (ML_LANE2N), U2.20 (LnC-)
/DP3+: DA1.2 (IO2), DA1.9, J1.3 (ML_LANE3P), U2.24 (LnD+)
/DP3-: DA1.1 (IO1), DA1.10, J1.1 (ML_LANE3N), U2.23 (LnD-)
/DP_AUX+: DA3.2 (IO2), DA3.9, J1.15 (AUXP), U2.13 (SBU1)
/DP_AUX-: DA3.4 (IO3), DA3.7, J1.17 (AUXN), U2.14 (SBU2)
/DP_HPD: DA3.5 (IO4), DA3.6, J1.18 (HPD)
/SBU1: D7.1 (A1), J2.A8 (SBU1), R6.1, U2.11 (CSBU1)
/SBU2: D5.1 (A1), J2.B8 (SBU2), R7.1, U2.12 (CSBU2)
/SSRx1+: DA4.2 (IO2), DA4.9, J2.B11 (SSRXp1), U2.1 (CRX1+)
/SSRx1-: DA4.1 (IO1), DA4.10, J2.B10 (SSRXn1), U2.2 (CRX1-)
/SSRx2+: DA6.2 (IO2), DA6.9, J2.A11 (SSRXp2), U2.9 (CRX2+)
/SSRx2-: DA6.1 (IO1), DA6.10, J2.A10 (SSRXn2), U2.10 (CRX2-)
/SSTx1+: C7.2, DA4.4 (IO3), DA4.7, J2.A2 (SSTXp1)
/SSTx1-: C8.2, DA4.5 (IO4), DA4.6, J2.A3 (SSTXn1)
/SSTx2+: C5.2, DA6.4 (IO3), DA6.7, J2.B2 (SSTXp2)
/SSTx2-: C6.2, DA6.5 (IO4), DA6.6, J2.B3 (SSTXn2)
/USB2_D+: D2.1 (A1), J2.A6 (Dp1), J2.B6 (Dp2), P1.3 (D+)
/USB2_D-: D3.1 (A1), J2.A7 (Dn1), J2.B7 (Dn2), P1.2 (D-)
/USB_DP_POL: R11.2, U1.14 (GPIO), U2.3 (POL)
GND: C1.2, C2.2, C3.2, C4.2, C9.2, C10.2, C11.2, C12.2, C13.2, D1.2 (A), D2.2 (A2), D3.2 (A2), D4.2 (A2), D5.2 (A2), D6.2 (A2), D7.2 (A2), DA1.3 (GND), DA1.8, DA2.3 (GND), DA2.8, DA3.1 (IO1), DA3.3 (GND), DA3.8, DA3.10, DA4.3 (GND), DA4.8, DA6.3 (GND), DA6.8, FL1.4, J1.2 (GND), J1.5 (GND), J1.8 (GND), J1.11 (GND), J1.16 (GND), J2.A1 (GND), J2.A12 (GND), J2.B1 (GND), J2.B12 (GND), L1.2, L2.1, L3.2, LEDPWR1.1 (K), P1.5 (GND), P2.4, R1.2, R2.2, R5.2, R6.2, R7.2, U1.25 (Vss), U2.29 (GND), U3.2 (GND)
unnamed: C3.1, U1.7 (Vccd)
unnamed: C12.1, U3.4 (BYP)
unnamed: CON1.1, FL1.1
unnamed: CON1.2, CON1.3, FL1.3
unnamed: J1.13 (CONFIG1), R1.1
unnamed: J1.14 (CONFIG2), R2.1
unnamed: J1.S (SHIELD), L1.1
unnamed: J2.S, L3.1
unnamed: L2.2, P1.6 (shield)
unnamed: LEDPWR1.2 (A), R3.2
unnamed: Q1.1 (G), R12.1, R13.1
unnamed: Q2.1 (G), R14.1, R15.1
unnamed: R4.2, R5.1, U1.17 (GPIO)
unnamed: R8.1, U1.3 (RD1)
unnamed: R9.2, U2.8 (AMSEL)

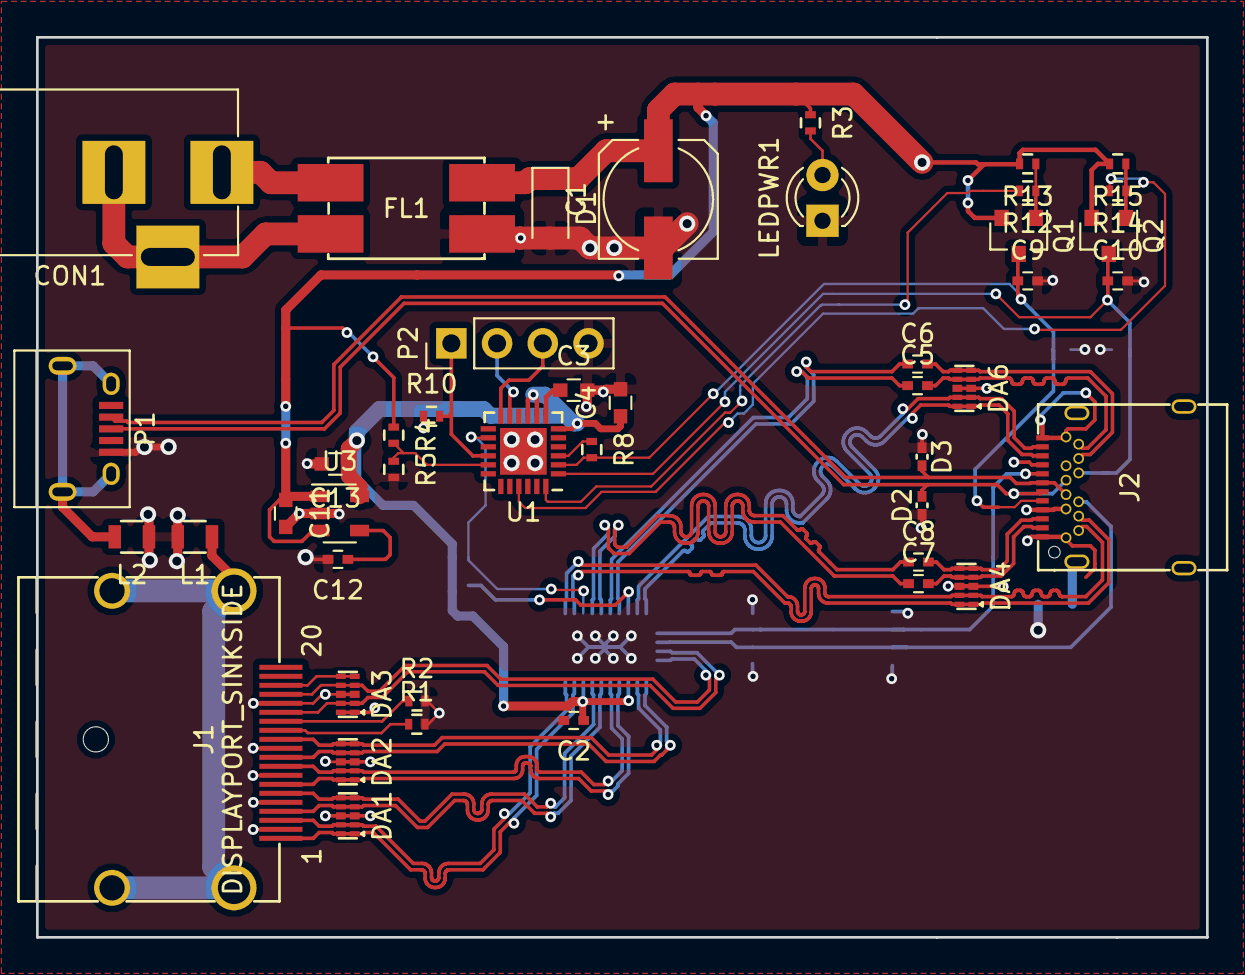
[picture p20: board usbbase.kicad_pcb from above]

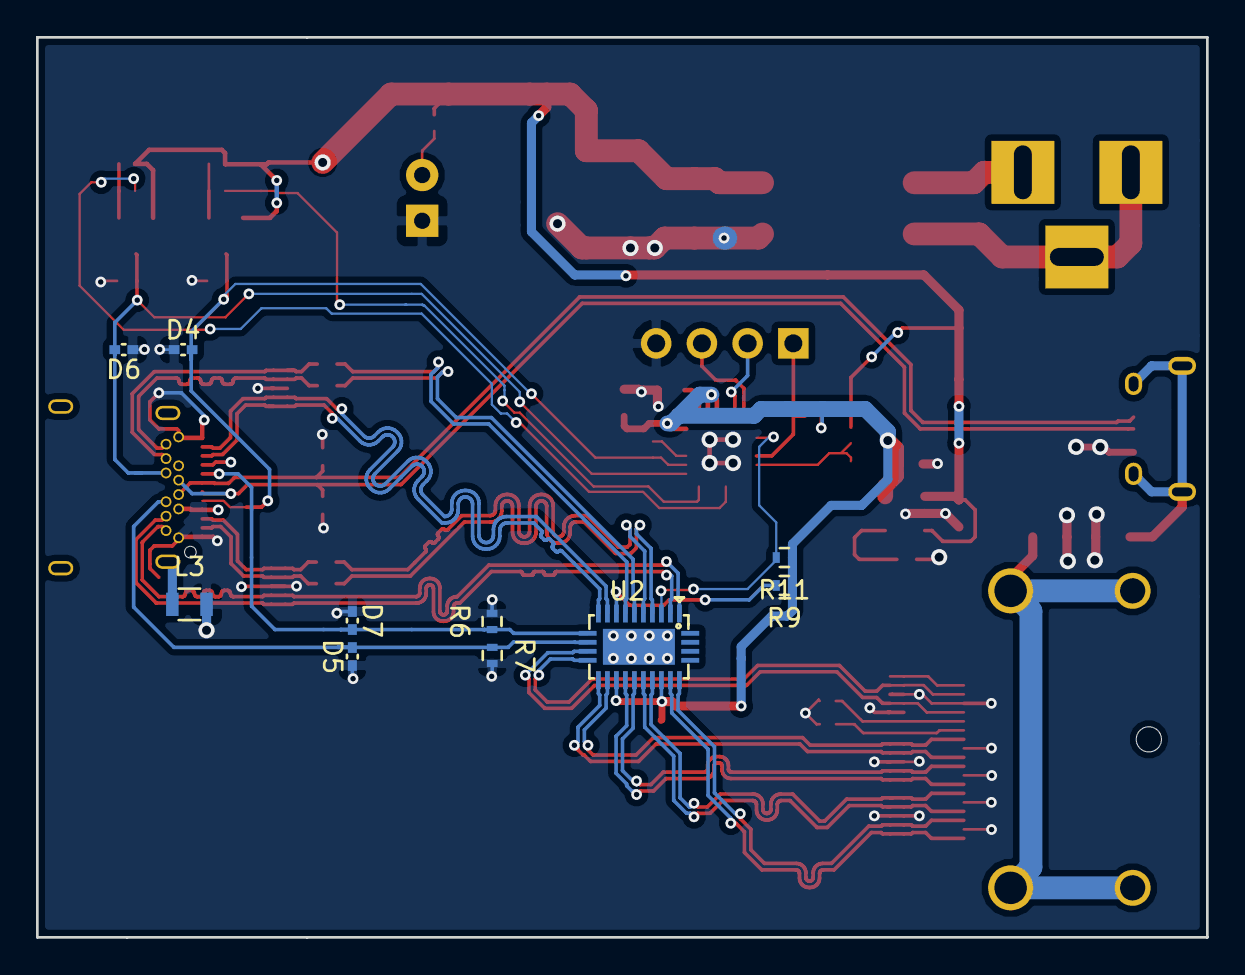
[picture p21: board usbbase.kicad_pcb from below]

Board: 4 copper layers, 65.0 x 50.0 mm, 55 parts (10 on the bottom side), 53 nets.

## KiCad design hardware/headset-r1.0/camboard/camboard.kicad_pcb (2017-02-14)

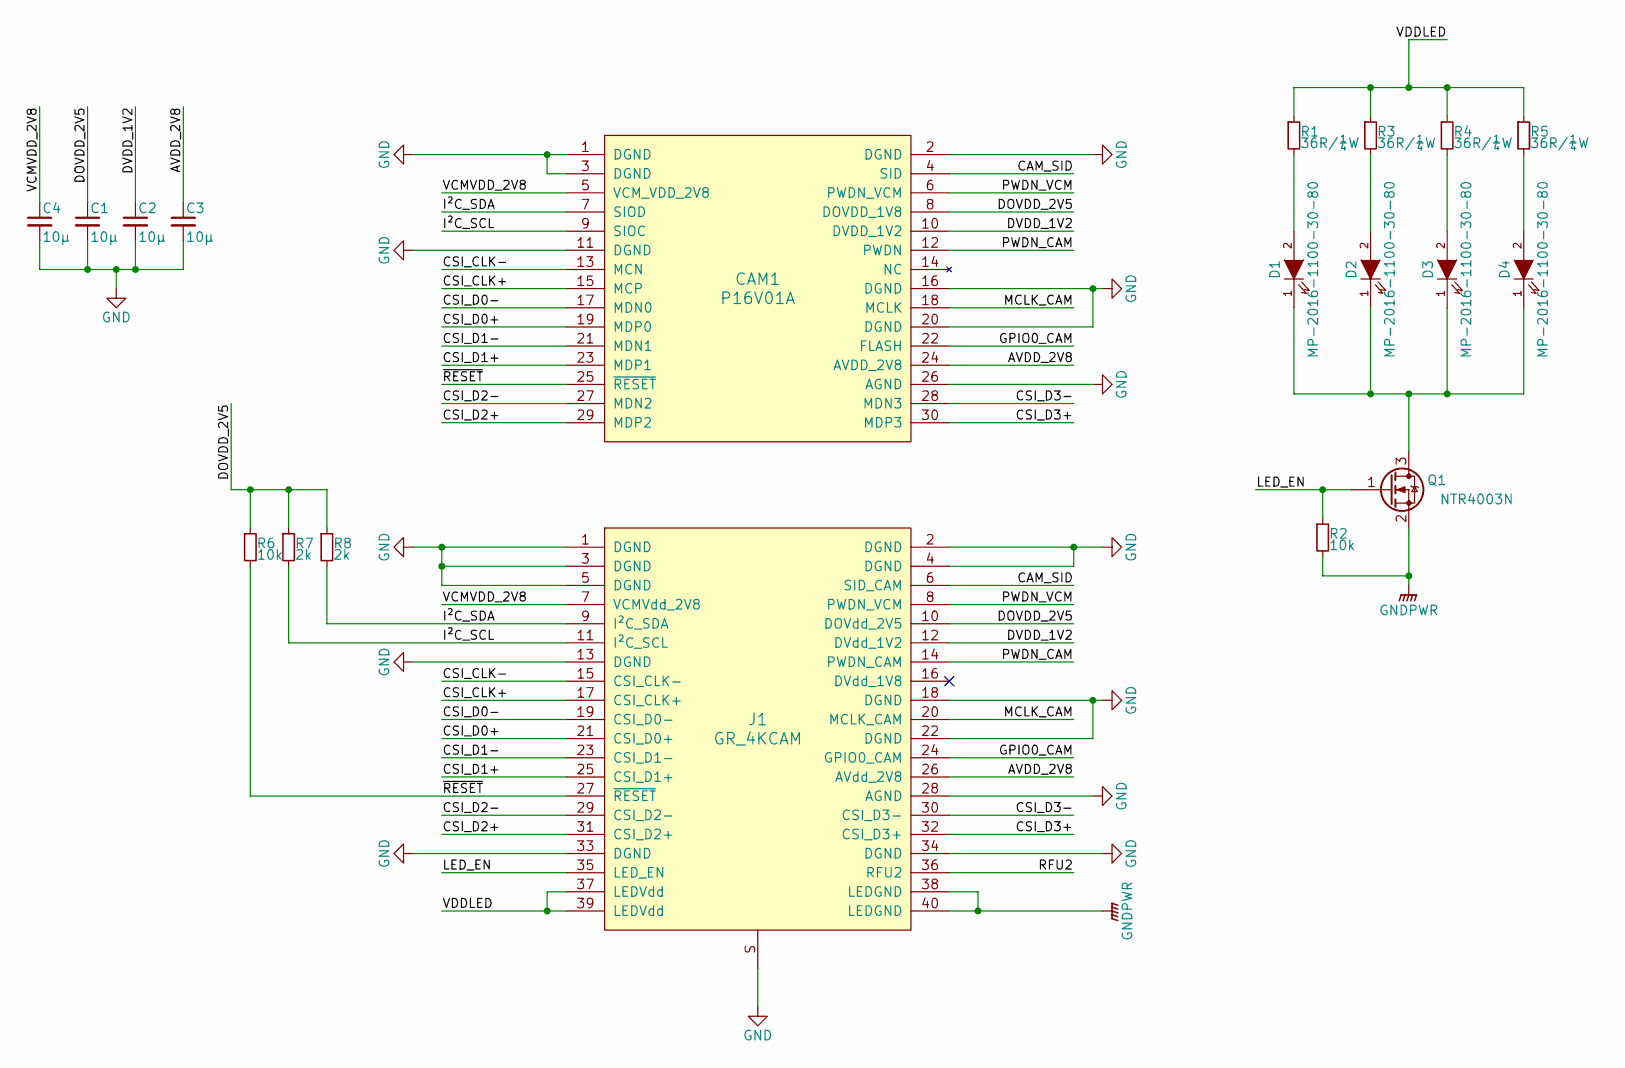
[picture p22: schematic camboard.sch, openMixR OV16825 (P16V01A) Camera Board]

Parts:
C1, C2, C3, C4: 10µ; C_0805
CAM1: P16V01A; P16V01A-503304-3040
D1, D2, D3, D4: MP-2016-1100-30-80; LED_MP2016
J1: GR_4KCAM; DF17(4.0)-40DP-0.5V(57)
Q1: NTR4003N; SOT-23
R1, R3, R4, R5: 36R/¼W; R_1206
R2, R6: 10k; R_0402
R7, R8: 2k; R_0402

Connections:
/AVDD_2V8: C3.1, CAM1.24 (AVDD_2V8), J1.26 (AVdd_2V8)
/CAM_SID: CAM1.4 (SID), J1.6 (SID_CAM)
/CSI_CLK+: CAM1.15 (MCP), J1.17 (CSI_CLK+)
/CSI_CLK-: CAM1.13 (MCN), J1.15 (CSI_CLK-)
/CSI_D0+: CAM1.19 (MDP0), J1.21 (CSI_D0+)
/CSI_D0-: CAM1.17 (MDN0), J1.19 (CSI_D0-)
/CSI_D1+: CAM1.23 (MDP1), J1.25 (CSI_D1+)
/CSI_D1-: CAM1.21 (MDN1), J1.23 (CSI_D1-)
/CSI_D2+: CAM1.29 (MDP2), J1.31 (CSI_D2+)
/CSI_D2-: CAM1.27 (MDN2), J1.29 (CSI_D2-)
/CSI_D3+: CAM1.30 (MDP3), J1.32 (CSI_D3+)
/CSI_D3-: CAM1.28 (MDN3), J1.30 (CSI_D3-)
/DOVDD_2V5: C1.1, CAM1.8 (DOVDD_1V8), J1.10 (DOVdd_2V5), R6.1, R7.1, R8.1
/DVDD_1V2: C2.1, CAM1.10 (DVDD_1V2), J1.12 (DVdd_1V2)
/GPIO0_CAM: CAM1.22 (FLASH), J1.24 (GPIO0_CAM)
/I²C_SCL: CAM1.9 (SIOC), J1.11 (I²C_SCL), R7.2
/I²C_SDA: CAM1.7 (SIOD), J1.9 (I²C_SDA), R8.2
/LED_EN: J1.35 (LED_EN), Q1.1 (G), R2.1
/MCLK_CAM: CAM1.18 (MCLK), J1.20 (MCLK_CAM)
/PWDN_CAM: CAM1.12 (PWDN), J1.14 (PWDN_CAM)
/PWDN_VCM: CAM1.6 (PWDN_VCM), J1.8 (PWDN_VCM)
/VCMVDD_2V8: C4.1, CAM1.5 (VCM_VDD_2V8), J1.7 (VCMVdd_2V8)
/VDDLED: J1.37 (LEDVdd), J1.39 (LEDVdd), R1.1, R3.1, R4.1, R5.1
/~RESET: CAM1.25 (~RESET), J1.27 (~RESET), R6.2
GND: C1.2, C2.2, C3.2, C4.2, CAM1.1 (DGND), CAM1.2 (DGND), CAM1.3 (DGND), CAM1.11 (DGND), CAM1.16 (DGND), CAM1.20 (DGND), CAM1.26 (AGND), J1.1 (DGND), J1.2 (DGND), J1.3 (DGND), J1.4 (DGND), J1.5 (DGND), J1.13 (DGND), J1.18 (DGND), J1.22 (DGND), J1.28 (AGND), J1.33 (DGND), J1.34 (DGND), J1.S
GNDPWR: J1.38 (LEDGND), J1.40 (LEDGND), Q1.2 (S), R2.2
unnamed: D1.1 (K), D2.1 (K), D3.1 (K), D4.1 (K), Q1.3 (D)
unnamed: D1.2 (A), R1.2
unnamed: D2.2 (A), R3.2
unnamed: D3.2 (A), R4.2
unnamed: D4.2 (A), R5.2

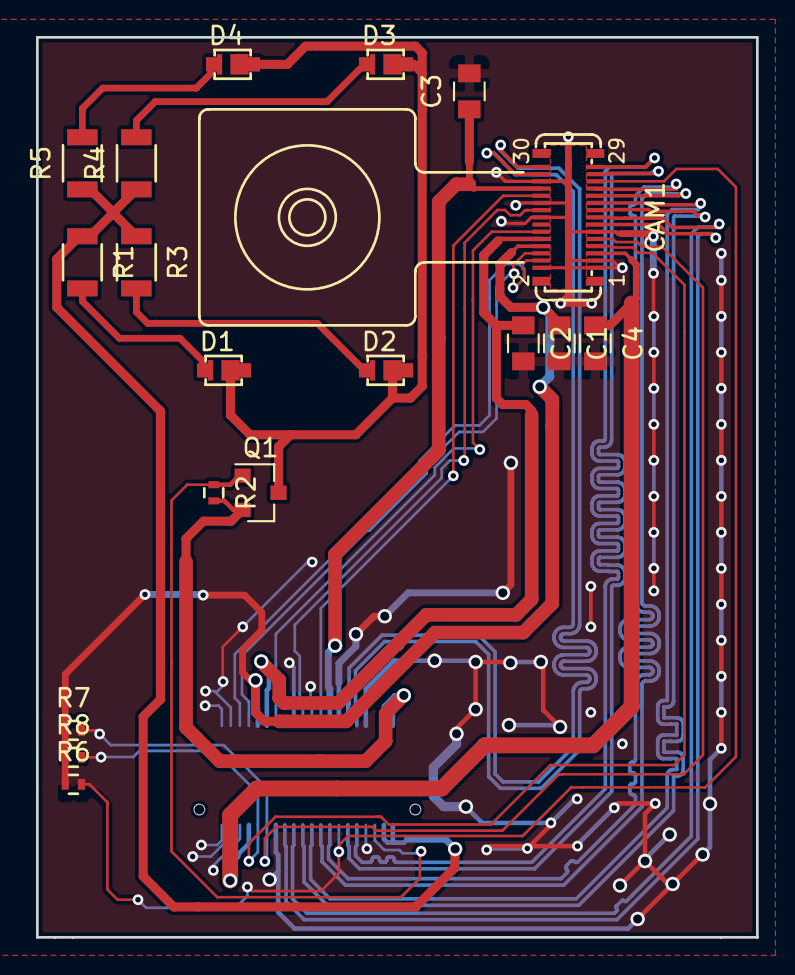
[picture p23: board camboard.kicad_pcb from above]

Board: 4 copper layers, 40.0 x 50.0 mm, 19 parts (1 on the bottom side), 31 nets.

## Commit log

2017-02-14 Add current hardware designs
    [IO.sch, a64.sch, a64_core_comm.sch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]
2017-05-04 Add LCD and camera submodules
2017-05-10 Add Gerbers for other boards, README tweaks
    [camboard-B.Cu.gbl, camboard-B.Mask.gbs, camboard-B.SilkS.gbo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]
